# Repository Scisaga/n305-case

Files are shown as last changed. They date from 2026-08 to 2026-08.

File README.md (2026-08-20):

# N305 主板机械参考与可打印外壳

没有厂商机械图纸，也不意味着设计新外壳只能靠“打印、打磨、再猜一次”。这个项目从原机照片、卡尺读数和 PCB 基准出发，重建一套**可以检查、修改并重新生成**的 N305 小主机机械模型。

项目目前已经走到可以试装的阶段：仓库里既有适合二次设计的 PCB/主板 STEP、STL 参考，也有可以直接切片验证的 V2 上下壳。V2 不是最终成品，而是一版用于发现问题、收集实物反馈的工程样机——已经确认的尺寸进入 CAD，仍待验证的参数也完整保留来源和状态，方便每一次试打都能推动模型继续收敛。

如果你手上也有这块主板，可以直接下载模型试装，也可以基于主板参考设计自己的外壳。尺寸反馈、接口照片和结构改进都很有价值。

<p align="center">
  <a href="https://delightlylinux.wordpress.com/2025/07/24/gmktec-g3-fun-while-it-lasted/">
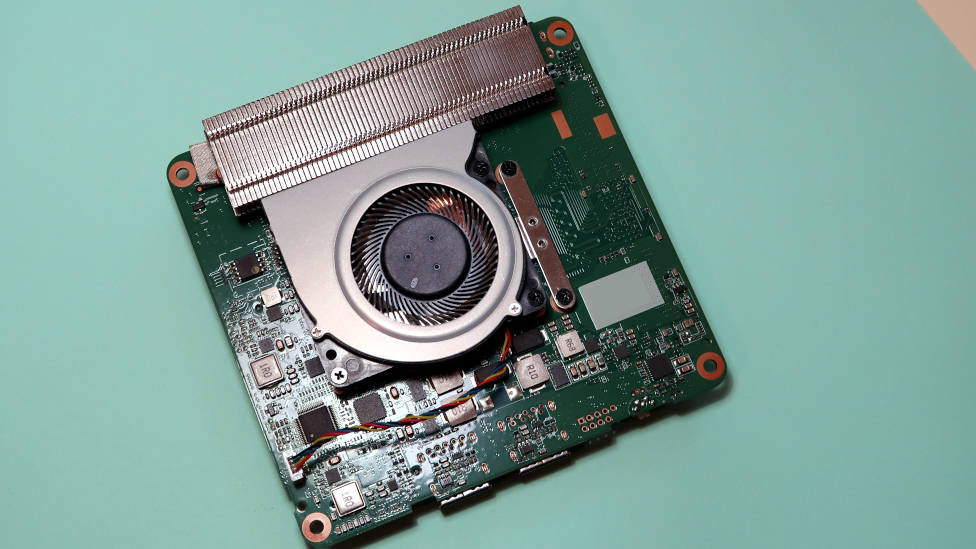
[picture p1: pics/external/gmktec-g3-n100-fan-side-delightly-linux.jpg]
GMKtec G3 主板的涡轮风扇与鳍片散热器一侧
    
  </a>
</p>

_外观参考：GMKtec G3 N100 版本主板的涡轮风扇与鳍片散热器一侧。图片来自 [Delightly Linux 原文](https://delightlylinux.wordpress.com/2025/07/24/gmktec-g3-fun-while-it-lasted/)；它与本项目重建对象布局相近，但不是本项目 N305 尺寸标定证据。机械尺寸仍以 `pics/` 中的用户实拍和卡尺数据为准。_

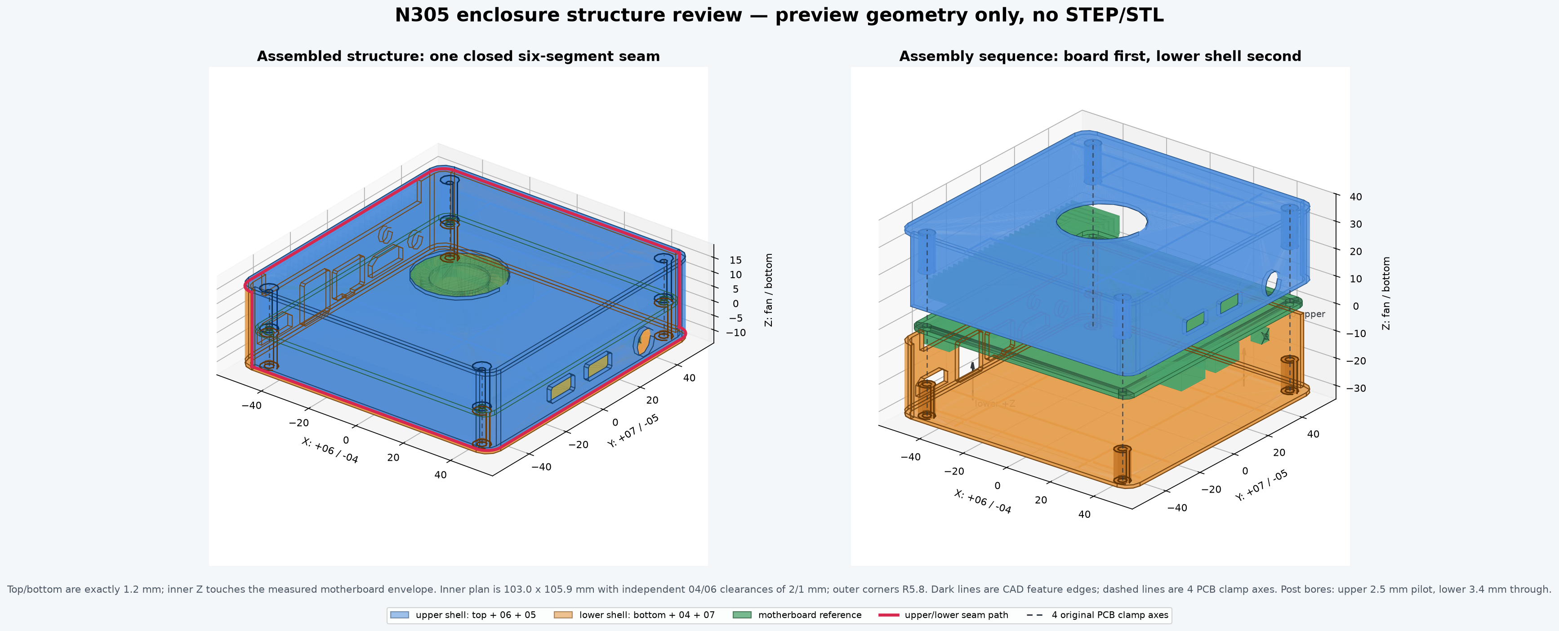
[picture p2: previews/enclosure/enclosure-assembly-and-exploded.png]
N305 V2 外壳装配与爆炸预览


_点击图片可在 GitHub 中打开 STL 交互预览；装配 STL 只用于检查，打印请使用独立的上壳和下壳文件。_

## 全程由 Codex 完成

这是一次用 [Codex](https://developers.openai.com/codex) 完成实体工程项目的实践。除实物拍摄、卡尺测量以及用户对方向和尺寸的确认外，照片证据整理、参数标定、建模代码、审阅图、STEP/STL 导出、自动验证和项目文档都由 Codex 在这个仓库中完成。

整个过程没有在 SolidWorks、Fusion 360、FreeCAD 等图形化专业 CAD 软件中手工建模或修补模型。Codex 编写并运行 Python/CadQuery 代码，底层使用 CadQuery、OpenCascade、Matplotlib、NumPy 和 Pillow 等开源程序库完成几何构造、图像处理和文件生成。因此，这里的 CAD 不是一组只能继续手工维护的成品文件，而是可以从参数和证据重新构建的程序化模型。

这也不是“一句话生成外壳”的演示。用户负责提供真实世界输入、识别明显错误并作出工程取舍；Codex 负责把这些反馈转化为参数、规则、代码和验证。最终结果来自多轮协作，而不是把 AI 的第一次推断当成答案。

## 快速入口

| 我想要…… | 从这里开始 |
| --- | --- |
| 直接试打 V2 外壳 | [上壳 STL](exports/enclosure/v2-prototype/n305_v2_upper_shell.stl) · [下壳 STL](exports/enclosure/v2-prototype/n305_v2_lower_shell.stl) · [试装说明](exports/enclosure/v2-prototype/README.md) |
| 选择材料和国内打印平台 | [V2 打印、下单与试装指南](docs/v2-printing-guide.md) |
| 修改 V2 外壳 | [上壳 STEP](exports/enclosure/v2-prototype/n305_v2_upper_shell.step) · [下壳 STEP](exports/enclosure/v2-prototype/n305_v2_lower_shell.step) · [参数源](src/n305_enclosure_structure.py) |
| 为主板设计自己的结构 | [完整主板 STEP](exports/reference/physical/n305_motherboard_reference.step) · [完整主板 STL](exports/reference/physical/n305_motherboard_reference.stl) · [主板模型说明](docs/motherboard-reference.md) |
| 检查尺寸和开孔依据 | [04 面参考](previews/reference/04-interface-reference.png) · [06 面参考](previews/reference/06-interface-reference.png) · [开孔覆盖检查](previews/enclosure/aperture-coverage-review.png) |
| 复现全部模型 | [构建脚本](scripts/) · [建模流程](docs/modeling-workflow.md) · [验证结果](exports/enclosure/v2-prototype/validation.json) |

## 当前进度

- [x] PCB 外形、四个原始安装孔和主板坐标系
- [x] 04/06 接口、板载开关和散热组件参考
- [x] 与物理实体分离的安装轴线和保守避让体
- [x] 面板开孔、圆角接缝和四孔夹紧结构审阅
- [x] 顶/底板 `1.5 × 0.8 mm` 内侧加强筋、器件绕行和碰撞审阅
- [x] V2 上壳、下壳及装配 STEP/STL
- [x] STEP 回读、STL 网格、实体边界和开孔覆盖自动验证
- [ ] V2 实物打印与同款主板装配反馈
- [ ] 收敛打印补偿、紧固件和按钮行程后发布制造版

## 方法与流程

这个项目最重要的产物不只是 STL，而是一套从不完整照片走向可审阅 CAD 的工作方法。顺序不能颠倒：先弄清楚证据说明了什么，再决定二维机械位置，最后才生成三维实体。

```mermaid
flowchart LR
    A[保存原始照片] --> B[记录实测与像素证据]
    B --> C[换算到统一 PCB 坐标]
    C --> D[生成正投影审阅图]
    D --> E{人工审阅}
    E -- 修正 --> B
    E -- 通过 --> F[生成 STEP / STL]
    F --> G[自动验证与实物试装]
    G -- 新实测 --> B
```

1. **保存原始证据**：原始照片保持不变，另外记录照片编号、观察方向、卡尺读数和可见轮廓。
2. **给数据分级**：明确区分用户实测、照片可读尺寸、PCB 对齐标定、轮廓证据和视觉推断；推断值必须标为 provisional。
3. **建立唯一坐标系**：以 `100.0 × 105.5 mm` PCB 和四个原始孔为机械基准，把照片信息换算成统一毫米坐标，不把画面边缘当作原点。
4. **先审二维机械图**：生成带 PCB 边界、方向、孔中心、尺寸和数据来源的正投影图，先检查接口位置与轮廓。
5. **审阅通过后再建三维**：CAD 直接读取毫米参数；物理实体、面板开孔、插头通道和保守避让体分开构造与导出。
6. **让验证成为模型的一部分**：回读 STEP、解析 STL，并检查包络、四孔、实体接触、开孔覆盖、壳体重叠和文件哈希。
7. **用试装结果闭环**：把装配松紧、接口插拔、按钮行程和紧固件结果重新写回参数，而不是只在 STL 上做一次性修补。

详细规则已经写入 [AGENTS.md](AGENTS.md)，完整操作见 [建模流程](docs/modeling-workflow.md)。这使后续 Codex 会话也必须遵守同一套坐标、数据优先级和审阅门。

## 走过的弯路

Codex 在早期重建中确实发生过多次漂移，用户的实测和审阅把模型拉回了正确轨道。这个过程也直接塑造了现在的方法论：

- 曾把照片透视和画面位置带入机械坐标，导致接口位置看似合理、实际基准却不可靠；后来强制所有位置先对齐 PCB。
- 曾把卡尺照片中的总包络差值平均分到 PCB 两侧，混淆了板宽和不同接口的突出量；后来改为按表面、按器件分别记录。
- 曾把通用 HDMI 代理当作真实接口鼻端，与已经确认的原壳六边形孔产生假冲突；现在未实测的真实轮廓明确标为“不计算”。
- 曾过早用简化形状替代散热器和风扇结构，也出现过看起来圆润但无法保持等壁厚、甚至不能完整包住 PCB 的外壳圆角方案。
- 曾在二维数据尚未稳定时直接推进三维，导致局部修正引发新的全局不一致；现在任何对象都必须先通过对应审阅门。

这些问题没有只靠修改最终模型掩盖。每次纠正都被固化成参数来源、生成规则或自动检查，目的是让同一种错误不再悄悄回来。仓库中的审阅记录因此不是附属文档，而是模型可信度的一部分。

## 设计预览

04 面的接口不是从照片像素直接描进 CAD，而是先换算到统一 PCB 坐标，再生成正投影审阅图：

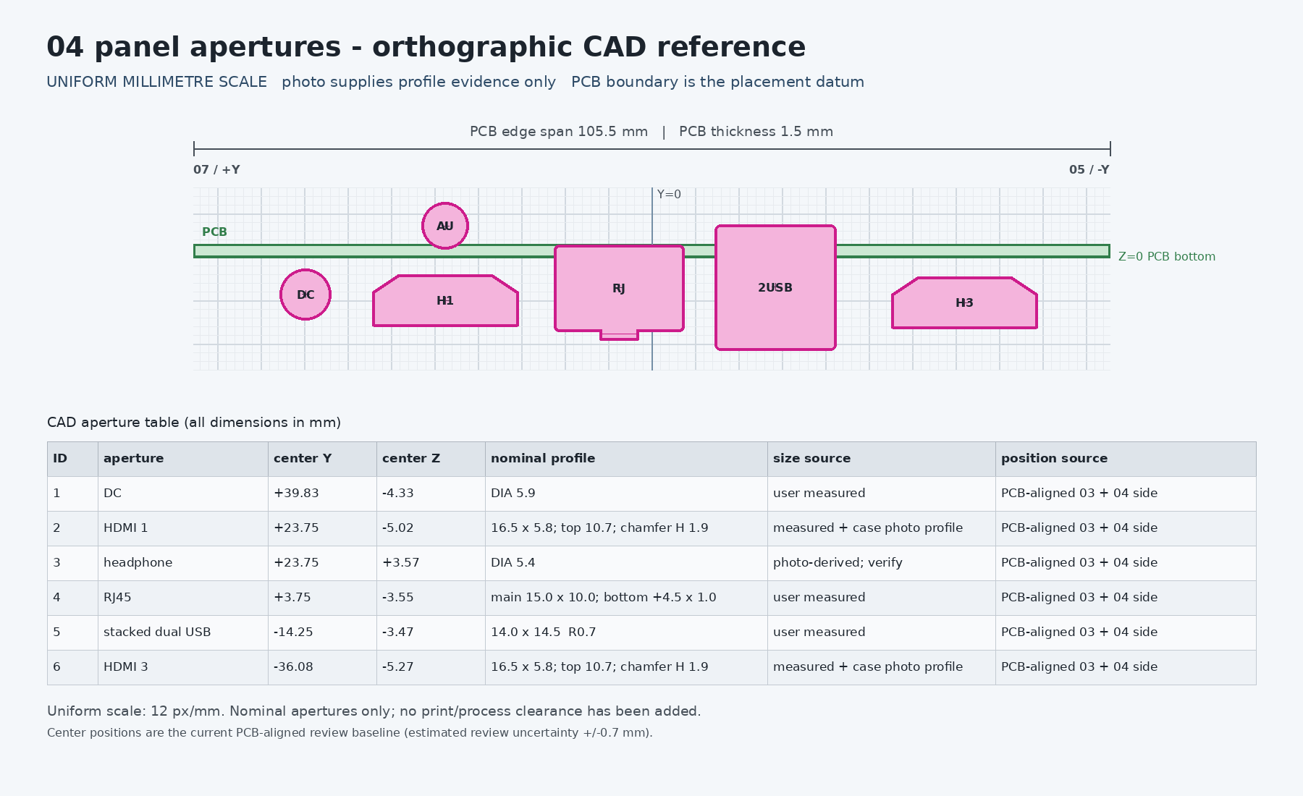
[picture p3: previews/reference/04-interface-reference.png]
04 面接口正投影审阅图


上下壳直接使用主板原有四孔定位和夹紧，不额外增加四颗外壳安装螺丝：

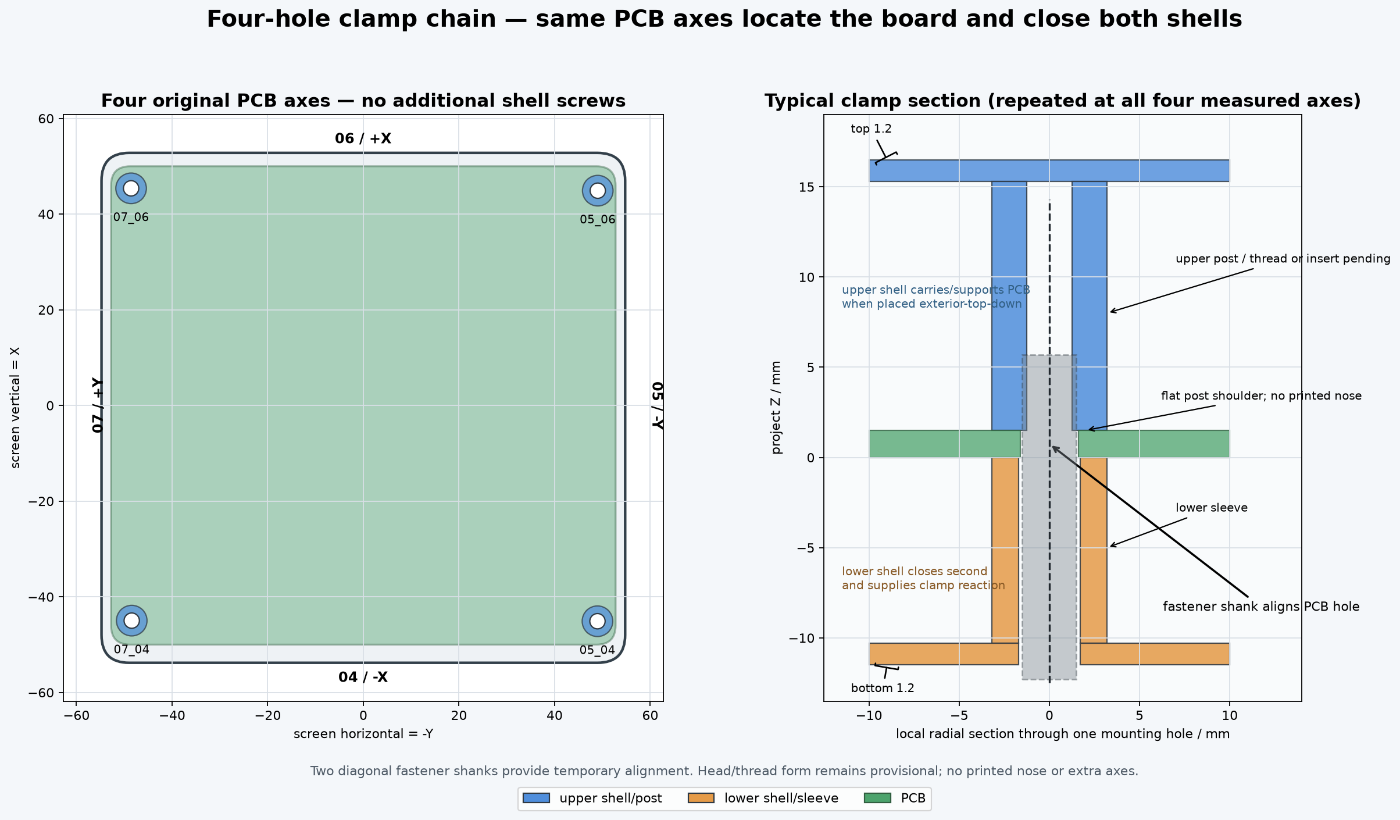
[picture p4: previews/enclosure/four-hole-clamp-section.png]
四孔夹紧结构剖面


顶板和底板的内侧加强筋也不是按外观随意布置。蓝色筋路已经用精确三维实体检查：顶筋绕过完整风扇蜗壳和鳍片，底筋绕过最低的 04 堆叠双 USB，并同时与完整主板参考进行碰撞审计。当前所有交叠体积均为 `0.000 mm³`。

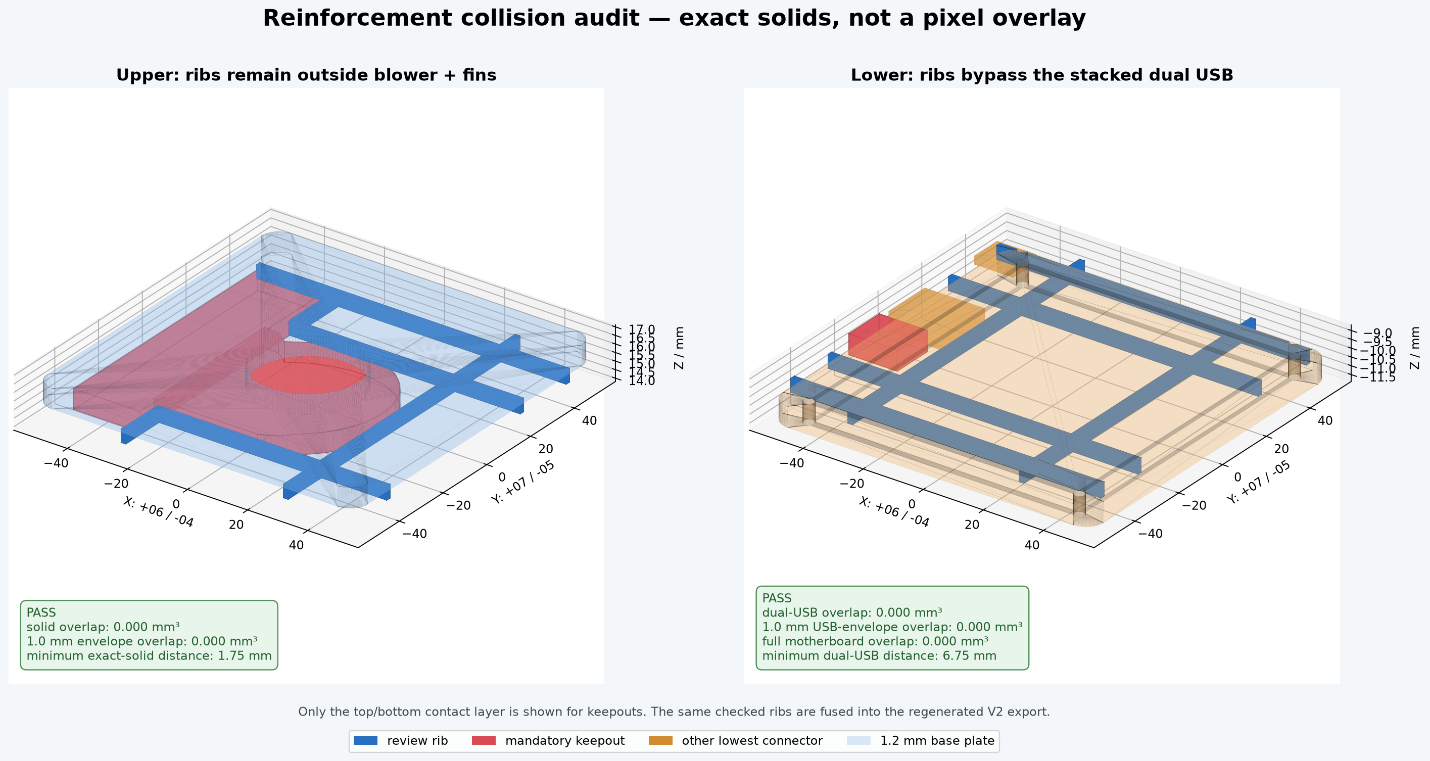
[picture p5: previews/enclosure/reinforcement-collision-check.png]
顶板和底板加强筋实体碰撞检查


具体筋路、尺寸和最短距离见 [加强筋审阅](docs/enclosure-reinforcement-review.md)。

更多结构图见 [外壳结构审阅](docs/enclosure-structure-review.md)，主板风扇、鳍片和散热接触关系见 [主板模型说明](docs/motherboard-reference.md)。

## 坐标与表面命名

项目文档中的 `04`、`05`、`06`、`07` 来自照片和实物表面的统一编号。正对风扇面、鳍片朝下时：

```text
                    06 / +X
                       ↑
          07 / +Y  ←  PCB  →  05 / -Y
                       ↓
                    04 / -X

             +Z 朝风扇，PCB 底面 Z=0
```

照片编号与观察方向见 [照片索引](pics/README.md)。所有 CAD 均使用毫米，并保持同一套装配坐标。

## 哪些尺寸可以相信

这个仓库刻意保留每项数据的来源和确定程度，不把视觉估算包装成精确测量。发生冲突时，用户实测和卡尺读数优先于照片标定，照片轮廓又优先于纯视觉推断。

当前 PCB 平面为 `100.0 × 105.5 mm`。PCB 外形、原始安装孔、接口中心和总 Z 包络用于机械定位；连接器隐藏壳体、PCB 圆角、散热器局部细节以及底面器件避让体仍包含照片重建或保守近似，不能当作厂商原始 CAD。

V2 外壳中的侧壁厚度、部分结构间隙、紧固件方案、打印补偿和按钮有效行程仍需要实物试装确认。完整参数及状态见 [V2 试装说明](exports/enclosure/v2-prototype/README.md)；数据权威顺序和建模规则见 [AGENTS.md](AGENTS.md)。

## 本地复现

需要 Python 3.11 或更高版本。以下命令会建立本地环境，并从参数和照片证据重新生成审阅图、主板模型与 V2 外壳：

```bash
python -m venv .venv
.venv/bin/python -m pip install -e .
PYTHONPATH=src .venv/bin/python scripts/calibrate_photos.py
PYTHONPATH=src .venv/bin/python scripts/calibrate_components.py
PYTHONPATH=src .venv/bin/python scripts/render_mainboard_reference.py
PYTHONPATH=src .venv/bin/python scripts/build_motherboard_reference.py
PYTHONDONTWRITEBYTECODE=1 PYTHONPATH=src .venv/bin/python scripts/build_enclosure_structure_review.py
PYTHONDONTWRITEBYTECODE=1 PYTHONPATH=src .venv/bin/python scripts/build_enclosure_reinforcement_review.py
PYTHONDONTWRITEBYTECODE=1 PYTHONPATH=src .venv/bin/python scripts/build_v2_prototype_enclosure.py
```

生成过程不仅导出 STEP/STL，也会回读 STEP、解析 STL 网格并写出验证 JSON。模型、参数和审阅材料分别放在：

- `src/`：机械参数和几何构造
- `scripts/`：标定、渲染、导出与验证入口
- `pics/`：原始照片证据
- `previews/`：适合人工审阅的正投影和结构图
- `exports/`：STEP、STL、参数清单与机器验证结果
- `docs/`：方法、数据来源和审阅记录

## 参与试装

当前最有价值的贡献是真实装配反馈。开始前请先阅读 [V2 试装建议](exports/enclosure/v2-prototype/README.md)，并尽量同时记录打印机、材料、层高和切片补偿。重点需要确认：

- 04/06 方向的壳体间隙，以及 05/07 方向的插入阻力
- 四个主板孔与上下壳柱体是否同轴
- USB、HDMI、RJ45、DC 和耳机插头能否顺畅插拔
- 原机圆形按钮的安装、行程和回弹
- 实际采用的螺钉、螺纹或热熔螺母方案

请不要为了“看起来能装”而默默修改模型；把实测值、测试条件和对应表面一起留下，下一版才能真正比这一版更可靠。

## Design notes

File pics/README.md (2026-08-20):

# N305 主板照片的视图与空间关系

本文说明本目录照片之间的空间关系，并为照片标定、尺寸提取和 CAD 建模提供统一方向。照片拍摄时存在旋转，**照片画面的上、下、左、右不等于主板的统一物理方位**；判断空间关系时以本页的“风扇面基准视图”为准。

## 1. 已确认的风扇面基准视图

正对风扇、热管和散热模组所在的元件面，并将散热鳍片转到下方。此时四条边的位置已经确认如下：

```text
                         上：06（双 USB 边）
                                CAD +X
                                   ↑
                                   │
 左：07（左边侧视）   CAD +Y  ←── 主板 ──→  CAD -Y   右：05（右边侧视）
                                   │
                                   ↓
                                CAD -X
                 下：04（后置 I/O、散热鳍片/出风边）

 +Z：离开 PCB，朝向观察者、风扇和热管
 -Z：穿过 PCB，朝向底面器件、M.2/内存插槽一侧
```

最重要的方位关系是：

- 左边是 07，上边是 06，右边是 05，下边是 04。
- 散热鳍片位于下方，即 04 所在边；04 同时是主要后置 I/O 边。
- 04 与 06 互为对边，05 与 07 互为对边。

### 与现有 CAD 坐标的关系

旧模型曾沿用原始照片方向，相对上述基准视图旋转了 90°。当前统一使用下列 CAD 坐标，不再保留旧生成器：

- CAD +X 指向基准视图上方的 06，CAD -X 指向下方的 04。
- CAD +Y 指向基准视图左方的 07，CAD -Y 指向右方的 05。
- `PCB_X = 100.0 mm` 对应基准视图的上下方向，即 06—04 方向。
- `PCB_Y = 105.5 mm` 对应基准视图的左右方向，即 07—05 方向。
- CAD +Z 指向风扇面，CAD -Z 指向主板底面。

坐标原点可取 PCB 平面中心；PCB 上、下表面的具体 Z 值由装配基准决定。

## 2. 六个面的对应关系

| 面或边 | 在风扇面基准视图中的位置 | 相机所在方向 | 观察方向 | 对面 | 识别特征 |
| --- | --- | --- | --- | --- | --- |
| 元件/风扇面 | 正面 | +Z | 沿 -Z 俯视 | PCB 底面 | 鼓风机、热管、长条散热鳍片 |
| PCB 底面 | 背面 | -Z | 沿 +Z 仰视 | 元件/风扇面 | M.2/内存插槽、纽扣电池及底面器件 |
| 04 边 | 下 | -X | 沿 +X 观察 | 06 边 | 后置 I/O 集中；散热鳍片和主要出风口位于此边 |
| 06 边 | 上 | +X | 沿 -X 观察 | 04 边 | 两个蓝色 USB-A 接口是最明显标志 |
| 05 边 | 右 | -Y | 沿 +Y 观察 | 07 边 | 主板右边的高度和侧面轮廓 |
| 07 边 | 左 | +Y | 沿 -Y 观察 | 05 边 | 主板左边的高度和侧面轮廓 |

因此有三组严格相反的观察方向：

- 元件/风扇面（+Z）与 PCB 底面（-Z）。
- 下边 04（-X）与上边 06（+X）。
- 右边 05（-Y）与左边 07（+Y）。

从风扇面翻到 PCB 底面后，左右关系会镜像。用底面照片标定孔位或器件位置时，应先通过四条已编号的边重新定向，不能直接沿用风扇面照片的画面左右坐标。

## 3. 照片与观察方向

| 照片 | 观察方向 | 内容与用途 |
| --- | --- | --- |
| [01-n305-mainboard-component-side-overall-width-measurement.jpg](./01-n305-mainboard-component-side-overall-width-measurement.jpg) | +Z → -Z | 风扇面整体尺寸；CAD X / 基准视图上下方向测量 |
| [02-n305-mainboard-component-side-overall-depth-measurement.jpg](./02-n305-mainboard-component-side-overall-depth-measurement.jpg) | +Z → -Z | 风扇面整体尺寸；CAD Y / 基准视图左右方向测量 |
| [03-n305-mainboard-bottom-side-overview.jpg](./03-n305-mainboard-bottom-side-overview.jpg) | -Z → +Z | PCB 底面总览；与风扇面互为正反面 |
| [04-n305-mainboard-bottom-rear-io-heatsink-edge-height-measurement.jpg](./04-n305-mainboard-bottom-rear-io-heatsink-edge-height-measurement.jpg) | -X → +X | 基准视图下边侧视；后置 I/O、鳍片/出风边及 Z 向高度 |
| [05-n305-mainboard-right-edge-height-measurement.jpg](./05-n305-mainboard-right-edge-height-measurement.jpg) | -Y → +Y | 基准视图右边侧视和 Z 向高度；与 07 相对 |
| [06-n305-mainboard-top-dual-usb-edge-height-measurement.jpg](./06-n305-mainboard-top-dual-usb-edge-height-measurement.jpg) | +X → -X | 基准视图上边侧视；双 USB 边及 Z 向高度；与 04 相对 |
| [07-n305-mainboard-left-edge-profile.jpg](./07-n305-mainboard-left-edge-profile.jpg) | +Y → -Y | 基准视图左边侧视和侧面轮廓；与 05 相对 |
| [08-n305-mainboard-component-side-blower-span-measurement.jpg](./08-n305-mainboard-component-side-blower-span-measurement.jpg) | +Z → -Z | 风扇面局部尺寸，记录鼓风机区域跨度 |
| [09-n305-mainboard-component-side-heatsink-span-measurement.jpg](./09-n305-mainboard-component-side-heatsink-span-measurement.jpg) | +Z → -Z | 风扇面局部尺寸，记录散热模组跨度 |
| [10-n305-mainboard-component-side-fin-stack-span-measurement-01.jpg](./10-n305-mainboard-component-side-fin-stack-span-measurement-01.jpg) | +Z → -Z | 鳍片区域跨度测量，第一张读数参考 |
| [11-n305-mainboard-component-side-fin-stack-span-measurement-02.jpg](./11-n305-mainboard-component-side-fin-stack-span-measurement-02.jpg) | +Z → -Z | 同一区域的第二张读数参考，用于交叉检查 |
| [机箱盒子04.jpg](./机箱盒子04.jpg) | 04 原机面板的一侧 | 反查 HDMI、RJ45、叠层窗口和 DC 的实际壳体开孔；其画面水平方向与产品外观图镜像 |
| [机箱盒子06.jpg](./机箱盒子06.jpg) | 06 原机外侧 | 反查两个 USB 开孔和已安装圆形按钮的位置/可见直径 |
| [机箱按钮-1.jpg](./机箱按钮-1.jpg) | 原机按钮正面 | 恢复圆帽与止挡法兰直径比例 |
| [机箱按钮-2.jpg](./机箱按钮-2.jpg) | 原机按钮侧面 | 恢复圆帽凸出和法兰厚度；后端推杆被便签遮挡 |

08～11 都是从 +Z 方向拍摄的局部测量照片，不是新增的独立表面。

### 第三方外观参考

| 本地副本 | 原始来源 | 用途与限制 |
| --- | --- | --- |
| [external/gmktec-g3-n100-fan-side-delightly-linux.jpg](./external/gmktec-g3-n100-fan-side-delightly-linux.jpg) | [Delightly Linux：GMKtec G3 – Fun While It Lasted](https://delightlylinux.wordpress.com/2025/07/24/gmktec-g3-fun-while-it-lasted/) · [原图](https://delightlylinux.wordpress.com/wp-content/uploads/2025/07/g3_rip05.jpg) | GMKtec G3 **N100** 版本主板的风扇/鳍片侧外观参考；不是本项目 N305 的尺寸标定证据，不进入像素测量或 CAD 参数源。 |

本地副本保持原图 `976 × 549` JPEG，SHA-256 为 `a1707353513bc608e8bfbca7035629bb3766b3975cc5d1438e5a57a8070ad939`。来源页面未展示明确的开放再许可条款，因此 README 必须保留来源链接和第三方属性；若来源方提出要求，应删除本地副本并恢复为外链展示。

## 4. Z 向堆叠关系

从 +Z 到 -Z，主板组件大致按以下顺序排列：

```text
最高处：风扇壳体、散热模组                 +Z
        热管、风扇、鳍片
        PCB 元件面
        PCB，厚约 1.5 mm
        PCB 底面器件、插槽及 SSD 避让区
最低处：底面最大下探器件                   -Z
```

当前项目使用的实测/建模值为：

- PCB 元件面至风扇最高面约 13.8 mm。
- PCB 厚度约 1.5 mm。
- PCB 底面至最低器件为 10.25 mm（04 原图换算值 10.246 mm）。
- 裸组件建模厚度为 25.55 mm，卡尺读数约 25.6 mm。
- 01 图约 `100.0 mm`、02 图约 `105.5 mm` 的卡尺读数确认 PCB 平面尺寸；卡爪位于角部，不能据此得到接口最大包络，也不能把差值对称分配给 04/06。
- 当前用户粗测为：04 双 USB 是该面最突出接口，约超出 PCB `2.0 mm`；06 两个 USB 约超出 `1.0 mm`；04 鳍片不超出 PCB。其余 04 接口只确认“略凸”，逐件突出量仍为 provisional。

散热气流的主要空间关系是：鼓风机从 +Z 侧吸气，经鳍片后朝基准视图下方的 04 边排出；在 CAD 中该方向为 -X。因此 V0.2 顶面圆孔直接对准风扇进气口，04 面设置与鳍片对齐的宽排风窗口；出风路径上不设置封闭横梁或小孔阵列。

01 照片中的风扇外壳已按 PCB 四角校正后描摩为非对称蜗壳，原始轮廓证据见 [01-blower-profile-trace.png](../previews/calibration/01-blower-profile-trace.png)，机器转换记录见 [component-calibration.json](../docs/component-calibration.json)。旧版 58 × 57 mm 圆角矩形风扇壳和三根叶轮示意杆作废。

## 5. 建模和照片标定规则

1. 先把风扇面照片旋转到“鳍片朝下”的基准姿态，再判断左 07、上 06、右 05、下 04。
2. 把基准视图方位录入现有 CAD 时使用转换关系：上/下对应 ±X，左/右对应 ±Y。
3. 使用底面照片时先做镜像关系检查，再通过接口组合或鳍片位置确认方向。
4. 两个相对侧视图的画面水平方向天然相反；比较接口位置时必须转换到同一个坐标系。
5. 03 底面照片先按 PCB 四条理论直边做透视校正，负责孔位和所有接口 XY；04、06 只负责 Z、接口正面形状和顺序。侧照片中的板边投影与接口不在同一深度，不能再拿来直接换算 Y。
6. 卡尺存在遮挡和透视误差；01、02 用于 PCB 平面尺寸，不能当成接口鼻端总包络。不同 Z 高度的接口和鳍片还会产生不同俯拍视差，不能直接用 PCB 平面单应结果反算突出量。08～11 用于局部尺寸和交叉验证。
7. 后续新增照片时，文件名应写明此基准下的方位和稳定特征，例如 `top-dual-usb-edge`、`bottom-rear-io-heatsink-edge`。
8. 完整像素坐标、换算式和辅助线叠图见 [../docs/photo-calibration.md](../docs/photo-calibration.md)。

## 6. 电源开关照片标定

03 底面照片透视校正并用 06 侧照片复核后，当前审阅基准为：

- 开关位于 06 边，与两个蓝色 USB-A 位于同一面。
- 开关中心为 `Y≈+29.5 mm`，沿 06 边距 07/06 角约 23.3 mm。
- 等价地，距 05/06 角约 82.3 mm。
- 开关中心约在 PCB 底面以下 4.2 mm。
- 可见开关正面约 4.5 × 4.5 mm，中央触点约 1.6～2.0 mm。

静态照片不能直接测得真实触发行程。原机 06 面照片和按钮照片支持恢复圆形按钮：可见帽约 Ø10.0 mm、止挡法兰约 Ø12.5 mm；用户实测穿过面板孔的按钮段为 **Ø9.2 mm**，原壳/新壳采用 **Ø9.4 mm** 配合孔。侧视照片中后端推杆被便签遮挡，不能从该图直接量取推杆长度。

[03 底面俯视照片](./03-n305-mainboard-bottom-side-overview.jpg) 与 [06 侧视照片](./06-n305-mainboard-top-dual-usb-edge-height-measurement.jpg) 共同确认：两个 USB 金属口构成06面的外侧接口基准；开关触点比 USB 前沿约向内退 `1.2 mm`（照片推定，暂记 ±0.4 mm），相邻 PCB 边还有局部台阶内缩。因此不能用 `100 mm` PCB 外接矩形的 `X=50` 直边直接推出开关触点位置，也不能把开关触点当作必须伸入 Ø9.4 墙孔的对象。按当前 USB 突出 `1.0 mm` 代理，开关触点暂置于 `X≈49.8 mm`；结合原壳 04–06 内距约 `103.0 mm`，06内墙暂置于 `X=51.0 mm`，两者约有 `1.2 mm` 静止轴向空间，后续由原按钮推杆跨越。

该标定取代早期“开关位于 05 边、距照片左边约 32 mm”的错误假设。

两只 USB-A 中心分别为 `Y≈+4.75 mm` 与 `Y≈-15.25 mm`。它们是同层安装的相同器件，因此机械参考共享 `Z=-3.14 mm`；此前 `-3.19/-3.09 mm` 的差值来自斜拍照片的透视推算，已经撤销。两个面板孔均采用用户确认的 **12.8 × 5.5 mm、R0.7** 水平圆角矩形；旧版 13.3/13.4 × 6.0 mm 以及 15.4 × 7.8 mm 孔作废。

## 7. 04 接口面的逐像素结论

[04-n305-mainboard-bottom-rear-io-heatsink-edge-height-measurement.jpg](./04-n305-mainboard-bottom-rear-io-heatsink-edge-height-measurement.jpg) 的卡尺主刻线拟合比例是 20.3 px/mm。结合主板照片与原机面板上方的接口图标，沿边组合确认是：DC、HDMI、RJ45、上下叠层双 USB-A、HDMI；此前把下层误认作 HDMI 的结论作废。

03 校正平面给出的中心 Y 为 `+39.83 / +23.75 / +3.75 / -14.25 / -36.08 mm`。这些中心对原机 04 面板五孔的线性拟合最大残差为 0.634 mm，所以中心位置保留。面板孔尺寸采用用户后续确认的实测值：DC **Ø5.9**；两只 HDMI **16.5 × 5.8** 原壳六边形，顶边 10.7、倒角高 1.9；叠层双 USB 共用 **14.0 × 14.5、R0.7** 圆角窗口；RJ45 主窗 **15.0 × 10.0**，其下方另加 **4.5 × 1.0** relief。原壳照片只用于确认非矩形轮廓，没有使用通用 HDMI 标准轮廓。

05、07 照片没有显示侧向插拔的用户接口，因此这两面保持封闭。

## 8. 与 V0.2 分壳的关系

V0.2 使用两个由三相邻面构成的互补角壳：

- 上壳：顶面、06、05，包含双 USB 和按键。
- 下壳：底面、04、07，包含后置接口和排风开口。

装板时先把 06 边 USB 斜向送入上壳窗口，再放平主板和安装下壳。四个 PCB 安装孔轴同时连接主板及两壳，不设置额外壳体螺丝位。04、06 各自保留一整面带贯通开孔的连续实体墙，不承担贴边定位；原壳实测 04–06 内距约 `103.0 mm`，结合 04/06 USB 最大突出量暂分配为 `2.0/1.0 mm`。05/07 仍各留 `0.20 mm` 紧凑试装余量；原壳约 `110.5 mm` 的 05–07 内距包含无需复制的额外留空。侧壁厚采用原壳实测 `1.8 mm`。连续内搭边和连续卡槽已经从方案中取消，六段异件边采用平面对接；详细结构见 [../docs/v0.2-reference-review.md](../docs/v0.2-reference-review.md)。

## 9. 关系确认状态

- 风扇面与 PCB 底面的正反关系：已确认。
- 风扇面基准视图中的左 07、上 06、右 05、下 04：已由实物方位确认。
- 散热鳍片位于下方 04 边，04 与 06 相对：已确认。
- 05 与 07 相对：已确认。
- 板载电源开关位于 06 边且偏向 07/06 一侧，当前中心 `Y≈+29.5 mm`：已由 03 校正平面与 06 局部比例交叉检查；像素标定中心误差估计约 ±0.35 mm。
- “后置 I/O”是本项目采用的功能名称；若厂商资料使用其他前后命名，编号 04～07 和上述空间关系仍保持不变。

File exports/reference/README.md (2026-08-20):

# 主板参考导出

本目录由 `scripts/build_motherboard_reference.py` 生成。所有模型使用毫米和项目唯一坐标系：`+X=06`、`-X=04`、`+Y=07`、`-Y=05`、`+Z=风扇面`，PCB 底面为 `Z=0`。

## physical

- `n305_motherboard_reference.step/.stl`：PCB、接口、板载开关和散热组件的总装参考。
- `n305_pcb.step/.stl`：带四个安装孔的 PCB。
- `n305_connectors_and_switch.step/.stl`：04/06 接口实体和板载电源开关。
- `n305_cooling_assembly.step/.stl`：冷板支撑、风扇托板、照片描摩蜗壳、32 片叶轮、热桥和鳍片；不含缺少侧视高度证据的双孔长条。

这些文件是用于机壳设计的物理参考，不是厂商制造模型。连接器隐藏壳体和散热组件细节含照片估计。接口 X 向前沿按对象保存：04 双 USB 约突出 PCB 2.0 mm、06 USB 约突出 1.0 mm、04 鳍片与 PCB 边齐平；04 其余接口当前 1.0 mm 前伸仅是 provisional 外观代理，不是实测值。

## clearances

- `n305_cooling_keepout.step/.stl`：风扇与鳍片上方保守包络。
- `n305_underside_keepouts.step/.stl`：底面器件的保守避让包络。
- `n305_mount_axes.step/.stl`：四个 PCB 孔的装配轴线。

避让体不能与 `physical` 文件合并后当作实物体积使用。

## validation.json

记录数据源、PCB/孔位、Z 包络、接口参数、各零件边界和散热接触检查。当前检查必须全部通过，且 `enclosure_geometry_generated` 必须为 `false`，表示本主板参考包不混入外壳实体；独立的 V2 外壳位于 `exports/enclosure/v2-prototype/`。

重新生成：

```bash
PYTHONPATH=src .venv/bin/python scripts/build_motherboard_reference.py
```

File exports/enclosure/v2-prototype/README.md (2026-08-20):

# N305 V2 试装版外壳

发布日期：2026-08-21
版本：`v2-prototype-2026-08-21-ribbed`
状态：**用于尺寸、接口和装配试装，不是最终量产版。**

材料选择、国内平台下单、切片方向、螺钉和收货验收见 [V2 外壳打印、下单与试装指南](../../../docs/v2-printing-guide.md)。

> 若已经把同名 STL 上传到打印平台，必须删除旧文件并重新上传本次生成文件。当前含筋版预览体积应约为：上壳 `24.13 cm³`、下壳 `23.02 cm³`；文件同名不表示平台中的旧上传已经更新。

## 文件

- `n305_v2_upper_shell.step/.stl`：上壳，顶面 + 06 + 05。
- `n305_v2_lower_shell.step/.stl`：下壳，底面 + 04 + 07。
- `n305_v2_enclosure_assembly.step/.stl`：上下壳闭合位置，仅用于总体检查；打印时使用两个独立 STL。
- `manifest.json`：完整参数、文件哈希和数据来源。
- `validation.json`：源实体、导入 STEP、STL 网格和装配检查。

所有 CAD 均为毫米，保留项目装配坐标：`+X=06, -X=04, +Y=07, -Y=05, +Z=风扇面`。原机圆形按钮作为复用件，不生成未经测量的按钮 STL。

## 当前试装结构

- 外包络：`106.6 × 109.5 × 28 mm`。
- 上下板厚均为 `1.2 mm`；没有额外风扇顶部避让。
- 顶板/底板内侧已融合 `1.5 × 0.8 mm` 稀疏加强筋；局部总厚度为 `2 mm`，外包络不变。顶筋绕过完整风扇/鳍片包络，底筋绕过 04 堆叠双 USB 和当前完整主板参考。
- 04/06 是连续实体墙；原壳实测内跨距约 `103.0 mm`，结合接口突出量暂分配为 04 侧 `2.0 mm`、06 侧 `1.0 mm`。
- 05/07 各保留 `0.20 mm` 紧凑试装余量；原壳约 `110.5 mm` 的内跨距包含额外留空，不复制到本版。
- 四周侧壁采用原壳实测 `1.8 mm`；这些侧面仍不承担主板主要定位，主板由原四孔/螺柱定位。
- 使用主板原有四孔夹紧上下壳；没有增加外壳专用螺钉轴。
- 04 面保留连续鳍片出风包络；05/07 不开侧向接口孔。
- STL 网格：线性公差 `0.04 mm`，角公差 `0.12 rad`。

## 全部 provisional / 试制参数

| 参数 | 当前值 | 状态 | 来源与限制 |
| --- | ---: | --- | --- |
| `inner_x_at_04_06` | 103.0 mm | user approximate measurement | original case: face 04 inner wall to face 06 inner wall |
| `inner_y_at_05_07` | 105.9 mm | fit-check design | PCB 105.5 + 0.2 mm allowance at faces 05 and 07; original-case 110.5 mm span deliberately not copied |
| `side_wall_thickness` | 1.8 mm | user measured | original case side wall; Not applied to panel aperture sizes. |
| `outer_plan_corner_radius` | 5.8 mm | derived provisional | inner PCB radius + side-wall thickness; Constant-thickness XY offset; replaces the invalid R10 corner. |
| `inner_plan_corner_radius` | 4.0 mm | provisional | photo-reconstructed motherboard corner radius; Must be replaced if a physical corner measurement differs. |
| `pcb_clearance_face_04` | 2.0 mm | derived provisional allocation | 2.0 mm maximum 04 USB projection and 103.0 mm measured inner span; Inner wall coincides nominally with the maximum USB front plane; it is not a PCB locating face. |
| `pcb_clearance_face_06` | 1.0 mm | derived provisional allocation | remaining 1.0 mm of the measured 103.0 mm inner span; Matches the 1.0 mm USB projection; the recessed switch is not the wall datum. |
| `pcb_clearance_face_05` | 0.2 mm | user-requested fit-check allowance | compact non-locating clearance; original-case 110.5 mm span includes unnecessary extra space |
| `pcb_clearance_face_07` | 0.2 mm | user-requested fit-check allowance | compact non-locating clearance; original-case 110.5 mm span includes unnecessary extra space |
| `original_button_through_diameter` | 9.2 mm | user measured | diameter of the original button portion that passes through the panel |
| `face_06_switch_tip_to_inner_wall` | 1.2 mm | photo-derived provisional | photo 03 places the switch behind the USB-defined wall datum; positive means no switch/wall penetration |
| `connector_front_span_04_to_06` | 103.0 mm | derived cross-check | PCB 100.0 + face-04 USB projection 2.0 + face-06 USB projection 1.0; equals the measured inner span |
| `button_inner_wall_to_switch_tip_range` | 0.8 × 1.6 mm | photo-derived estimated range | nominal 1.2 mm with +/-0.4 mm switch-plan uncertainty; excludes unquantified USB rough-measurement error |
| `button_outer_wall_to_switch_tip_range` | 2.6 × 3.4 mm | derived estimated range | 1.8 mm measured wall plus the inner-wall-to-switch range; original button must bridge this axial stack |
| `face_04_max_connector_projection` | 2.0 mm | user rough measurement | stacked dual USB maximum; not shared by every 04 connector |
| `face_04_other_connector_projection_proxy` | 1.0 mm | provisional | unmeasured 04 connector noses; Visual proxy only; DC, HDMI, headphone and RJ45 front projections are not individually measured. |
| `face_06_usb_projection` | 1.0 mm | user rough measurement | two USB front faces; independent from face 04 |
| `nominal_seam_gap` | 0.0 mm | design intent | flush review geometry |
| `manufacturing_seam_clearance` | 0.0 mm | not applied | no manufacturing gap is embedded in the review geometry; any future process compensation must be a separate parameter |
| `fin_exhaust` | 84.0 × 7.4 mm | functional envelope | current fin-stack projection; grille segmentation pending |
| `internal_reinforcement_rib_height` | 0.8 mm | fit-check design | selected after PA12 manufacturability and collision review; Added locally to the 1.2 mm inner plate faces; does not change the base plate thickness. |
| `internal_reinforcement_rib_width` | 1.5 mm | fit-check design | reviewed sparse rib paths; Upper paths bypass the blower/fins; lower paths bypass the stacked dual USB and complete motherboard reference. |
| `clamp_post_od` | 6.4 mm | provisional | review proposal |
| `upper_thread_pilot_diameter` | 2.5 mm | provisional | review proposal; Thread, heat-set insert or self-tapping strategy is not selected. |
| `lower_screw_clearance_diameter` | 3.4 mm | provisional | review proposal; No screw-head counterbore or countersink is included. |
| `printed_hole_locator_nose` | no  | review recommendation | removed: 3.0 OD around 2.5 pilot leaves only 0.25 mm radial wall |
| `fastener_family` | M3-class  | provisional | inferred from 3.2 mm PCB hole; Head, insert and thread form pending. |

## 尚未解决、必须通过实物试装确认

- 04/06 allocation is provisionally 2.0/1.0 mm from USB projections
- exact photo-derived contour of the local PCB step beside the face-06 switch; the current full PCB envelope is conservative for wall clearance
- physical confirmation of the provisional PCB R4 corner reference
- additional print/process compensation, if later required, must remain separate from the reviewed structural clearance
- M3-class screw head, insert and thread form
- reused external button cap geometry and effective travel
- headphone aperture physical diameter confirmation
- exact HDMI connector-front profile; generic motherboard proxy is excluded from aperture coverage
- 04 fin-exhaust grille segmentation inside the no-obstruction envelope

补充说明：两个 HDMI 沿用已审阅的原壳六边形贯通孔。由于真实 HDMI 金属鼻端轮廓尚未测量，它们不参与“通用鼻端代理”的覆盖判定，但也没有因此改变孔形。

## 自动验证摘要

- 上壳、下壳各为一个有效实体：`True`。
- 上下壳体积重叠为零：`True`。
- 两壳与 PCB 实体体积重叠为零：`True`。
- 04/06 开孔后仍为连续墙体：`True`。
- 内侧加强筋已完整融合且无主板碰撞：`True`。
- STEP 回读实体数与体积一致：`True`。
- STL 文件可解析且包含三角形：`True`。
- 名义开孔覆盖失败：`[]`。
- 未计算覆盖：`['04:hdmi_1', '04:hdmi_3']`。

## 试装建议

1. 本目录未提供独立测试片；下单时打印上、下壳两个独立 STL，不打印装配 STL。
2. 上壳建议外顶面朝打印平台；下壳建议外底面朝打印平台。支撑策略取决于材料和切片软件。
3. 不要先强行攻丝。先测量实际 M3 紧固件、打印孔收缩和原按钮行程，再决定扩孔、热熔螺母或自攻方案。
4. 试装反馈应分别记录 04/06 间隙、05/07 插入阻力、四孔同轴性、按钮回弹和每个插头的插拔空间。

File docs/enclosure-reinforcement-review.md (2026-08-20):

# N305 外壳内侧加强筋审阅

状态：**路径和高度已经审阅，并已进入重新生成的 V2 STEP/STL。**

## 输出

- [顶板/底板内侧平面图](../previews/enclosure/reinforcement-inner-plan.png)
- [三维碰撞检查图](../previews/enclosure/reinforcement-collision-check.png)
- [机器验证结果](enclosure-reinforcement-validation.json)

## 当前设计

- 顶板、底板基础厚度继续保持 `1.2 mm`。
- 筋宽 `1.5 mm`，筋高 `0.8 mm`；已选择 `0.8 mm` 而不是初稿 `0.5 mm`，以提高 PA12 MJF/SLS 成型稳定性。
- 顶筋绕过照片重建的完整风扇蜗壳和 `84 × 22 mm` 鳍片投影。
- 底筋绕过 04 面堆叠双 USB；下层 USB 最低约 `Z=-10.29 mm`，与底板内表面 `Z=-10.30 mm` 基本齐平，不能依赖高度错开。
- 同时检查当前完整主板实体及其他接近底板的接口代理，不能为了满足单一 USB 避让而制造新的干涉。
- `1.0 mm` 是本审阅使用的保守 XY 包络，不是已写入外壳的制造间隙。

## 碰撞结果

| 检查 | 结果 |
| --- | ---: |
| 顶筋 vs 风扇/鳍片实体 | `0.000 mm³` |
| 顶筋 vs 1.0 mm 散热审阅包络 | `0.000 mm³` |
| 顶筋 vs 完整主板参考 | `0.000 mm³` |
| 底筋 vs 堆叠双 USB | `0.000 mm³` |
| 底筋 vs 1.0 mm 双 USB 审阅包络 | `0.000 mm³` |
| 底筋 vs 完整主板参考 | `0.000 mm³` |
| 顶筋至散热实体最短距离 | `1.75 mm` |
| 底筋至双 USB 实体最短距离 | `6.75 mm` |

当前全部布置检查通过：`True`。

## 已确认的制造取舍

筋高最终采用 `0.8 mm`。基础顶板/底板仍是 `1.2 mm`；只有筋路位置的局部总厚度为 `2.0 mm`。路径或高度以后若再次变化，仍必须重新执行实体碰撞检查和 STEP/STL 回读验证。

本设计没有增加外部包络、没有改变风扇进气孔，也没有改变顶板/底板的基础厚度。

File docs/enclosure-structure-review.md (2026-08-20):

# N305 外壳结构定义审阅

更新日期：2026-08-21

状态：**结构检查已通过，并已按本参数源生成 V2 试装版 STEP/STL；尚不是最终量产版。**

本文件记录“外壳由哪些面组成、怎样装配、怎样夹紧、接缝在哪里、开孔能否覆盖功能区域”。同一参数源现已用于用户授权的 V2 试装版；预览图本身仍不是制造文件，实际 CAD 与全部试制参数见 [V2 伴随说明](../exports/enclosure/v2-prototype/README.md)。

## 1. 两个一体式三面壳

| 零件 | 一体连接的面 | 作用 |
| --- | --- | --- |
| 上壳 | 顶面、06、05 | 先接收并承托主板；顶面带风扇进气孔 |
| 下壳 | 底面、04、07 | 第二步闭合；04 带接口和鳍片出风，底面提供四孔紧固入口 |
| 原机按钮 | 复用，不重画未经测量的帽体 | 穿过 06 的 Ø9.4 孔触发板载开关 |

[装配与爆炸图](../previews/enclosure/enclosure-assembly-and-exploded.png)使用蓝色表示上壳、橙色表示下壳、绿色表示主板参考。

## 2. 包络和壁厚

| 参数 | 当前值 | 状态与依据 |
| --- | ---: | --- |
| 内腔宽 X / Y | 约 103.0 / 105.9 mm | X 为用户对原壳的实测；Y 为 PCB 105.5 + 05/07 各 0.20 mm 试装余量 |
| X 向外宽 | 106.6 mm | derived：内腔 103.0 + 两侧 1.8 mm 壁 |
| Y 向外宽 | 109.5 mm | derived：内腔 105.9 + 两侧 1.8 mm 壁 |
| 裸组件 Z 包络 | -10.3…+15.3 mm | 当前主板验证包络，合计 25.6 mm |
| 顶板 / 底板 | 1.2 / 1.2 mm | 用户确认，精确值 |
| 内侧加强筋 | 宽 1.5 / 高 0.8 mm | 已审阅并进入 V2；有筋处局部总厚度 2.0 mm |
| 壳体 Z 向外厚 | 28.0 mm | 25.6 + 1.2 + 1.2；没有风扇额外间隙 |
| 侧壁 | 1.8 mm | 用户对原壳的实测；不改变面板孔标称尺寸 |
| XY 外轮廓圆角 | R5.8 mm | derived provisional：内 R4 + 1.8 mm 壁厚，构成等壁厚偏置 |
| XY 内腔圆角 | R4 mm | provisional：照片重建的 PCB 圆角，尚无物理实测值 |

顶板和底板的 `1.2 mm` 是连续基础板厚，不因加强筋而改写。已批准的稀疏筋从内表面增加 `0.8 mm`：顶筋在 XY 平面绕开完整风扇蜗壳和鳍片投影，底筋绕开最低的 04 堆叠双 USB，并同时对当前完整主板实体检查。实体交叠均为 `0.000 mm³`；筋已经与各自壳体融合为单一有效实体，不增加外包络。路径、距离和三维审图见[加强筋审阅](./enclosure-reinforcement-review.md)。

04 和 06 都是连续实体侧壁，只从整面墙中切除已经审阅的贯通孔和 04 鳍片出风包络。它们不承担 PCB 贴边定位。原壳 04–06 内距约 `103.0 mm`，当前结合两侧最大 USB 突出量暂分配为：04 内壁 `X=-52.0 mm`（距 PCB `2.0 mm`），06 内壁 `X=+51.0 mm`（距 PCB `1.0 mm`）。这使两侧 USB 前沿分别成为对应墙面的局部轴向基准，而不是让板载开关伸进墙体。

原壳 05–07 内距约 `110.5 mm` 包含额外留空，用户明确认为不需要参考，因此不进入当前外壳尺寸。05/07 恢复为各 `0.20 mm` 紧凑试装余量，当前 Y 向内距为 `105.9 mm`。PCB 的主要 XY 定位与两壳夹紧仍由原有四孔/螺柱完成。这些侧向尺寸不是上下壳接缝，也不是额外打印补偿。

接口突出量不再共享一个对称平面：04 叠层双 USB 粗测约 `2.0 mm`，06 两个 USB 粗测约 `1.0 mm`，04 鳍片外沿与 PCB 齐平；04 其余接口暂用 `1.0 mm` provisional 代理。按当前分配，两侧最大 USB 前沿都与内墙面名义相齐，在 `1.8 mm` 厚墙孔内形成与原壳一致方向的退入式接口通道，而不是让接口主体穿透整面墙。

03 俯视和 06 侧视共同确认 06 墙面轴向关系应由两个 USB 约束；开关触点比 USB 前沿约内退 `1.2 mm`，当前代理位于 `X≈49.8 mm`，距 06 内墙 `X=51.0 mm` 约 `1.2 mm`，不会进入墙孔。开关附近 PCB 的局部内缩轮廓不能再被 `100 mm` 外接矩形替代。`Ø9.4 mm` 按钮孔覆盖的是 `Ø9.2 mm` 原按钮穿孔段，不是板载触点本体。侧壁厚也已复原为原壳实测 `1.8 mm`，因此按钮的穿墙长度条件比旧版 `1.2 mm` 假设更接近原件；按钮静止位置与有效行程仍需实物试按确认。

当前主板实体仍保留 `100 × 105.5 mm` 完整外包络作为保守碰撞体，没有凭照片猜切局部 PCB 台阶的精确轮廓；但开关实体和墙面基准已脱离这条虚构直边。因为完整外包络比真实内缩 PCB 更占空间，只要它与墙体无碰撞，补回真实台阶不会恶化外壳净空。后续若需要外观级主板复刻，再单独对 03 照片做局部正投影描边。

四孔进一步锁定了这个推导。04 侧两根安装轴到 `X=-52.0 mm` 内墙分别约为 `7.018/6.893 mm`；06 侧两根安装轴到 `X=+51.0 mm` 内墙分别约为 `5.613/6.105 mm`。上下壳的柱位读取这些原孔坐标后，主板不能再沿 X 平移，因而不会把开关意外推入按钮孔。同时，`100.0 + 2.0 + 1.0 = 103.0 mm`，PCB 与两侧最大 USB 前沿的总跨度恰好闭合原壳内距。

按钮轴向链的当前估算为：外墙到内墙 `1.8 mm`，内墙到触点名义 `1.2 mm`，所以外表面到开关触点名义约 `3.0 mm`。只计 03 照片给出的 `±0.4 mm` 平面不确定度，内墙到触点约为 `0.8–1.6 mm`，外表面到触点约为 `2.6–3.4 mm`；这里尚未计入 USB“约 1 mm”粗测误差。原按钮本来就是为 `1.8 mm` 原壳墙厚和该主板安装关系工作的，因此复用的几何可信度较高；唯一不能由现有照片直接证明的仍是被遮挡推杆的自由长度与实际触发行程。

主板参考中的隐藏连接器主体只是保守方盒，并非实测轮廓。把 04/06 面退到 PCB 边后，这些代理方盒会与面板发生名义交叠；本轮只记录该交叠，不用它擅自放大原壳孔。实体检查改为：PCB 本体与六面零体积穿插、非接口面与完整主板模型无交叠、外部孔仍按权威尺寸完成覆盖。真实连接器后部若影响最终壁厚，需要补充实测截面后再处理。

圆角是真实参数化实体，不是渲染修饰。先前的“外 R10 + 内 R4 + 小幅外扩”并不满足包含关系，而旧验证只检查体积相交，错误地给出通过。本版已经删除该组合。现在外轮廓是扩大后的内腔轮廓向外等距 `1.8 mm` 的结果，因此外圆角为 `R4 + 1.8 = R5.8`，直边和圆角的名义壁厚一致。R4 仍是待实测的 provisional 内腔圆角，不表示圆弧与 PCB 零间隙接触。

新增验证同时检查：完整 PCB 平面是否被扩大后的内腔包含、04–06 内跨距是否为 `103.0 mm`、05/07 是否各为 `0.20 mm`、侧壁是否为 `1.8 mm`、06 内墙是否采用 USB 前沿而非开关触点作为基准、非对称 X 边界是否正确平移整个圆角实体、外轮廓与内腔理论等距偏置是否双向一致，以及开孔后 04/06 是否仍各为一个连续墙体实体。这些项目不能再由“PCB 与壳体相交体积为零”替代。PCB R4 本身仍是照片近似，待实物测量后会联动更新内外两个圆角。

当前验证要求为：PCB 完全位于内腔中；04/06 分配为 `2.0/1.0 mm`，05/07 为 `0.20/0.20 mm`；理论等距偏置相对当前外轮廓的缺失和多余体积均为 `0.0 mm³`；直边壁厚和圆角径向壁厚均为 `1.8 mm`；04/06 开孔后分别保持单一连续实体。最终数值以本轮重新生成的 [内部验证](./enclosure-structure-validation.json) 为准。

## 3. 一条闭合六段接缝

上下壳的边界是一条闭合路径：

```text
顶面—04 → 顶面—07 → 06—07 竖角 → 底面—06
     → 底面—05 → 04—05 竖角 → 回到顶面—04
```

- 两个右侧圆角（06/07、06/05）完整归 06/上壳；两个左侧圆角（04/07、04/05）完整归 04/下壳，任何圆角曲面上都没有分件缝。
- 06/07 竖缝退到 `X=+47.0 mm` 的 +Y 直边切点；04/05 竖缝退到 `X=-48.0 mm` 的 -Y 直边切点。两值不再强制关于原点对称，因为 04/06 单侧分配是 `2.0/1.0 mm`。
- 顶面/04、顶面/07、底面/06、底面/05 使用齐平对接；圆角转弯属于对应的完整单壳实体。
- 上壳内部的顶面—06—05，以及下壳内部的底面—04—07，均为同一零件的连续连接，不是装配缝。
- 当前名义 CAD 缝隙为 `0.0 mm`，没有嵌入制造补偿。若以后打印工艺确实需要补偿，必须另设参数并再次审阅，不能污染零间隙结构基准。
- 不使用连续卡槽、连续内搭边、整圈舌槽或独立框架。

详见 [六面归属和接缝图](../previews/enclosure/face-ownership-and-seam.png)。

爆炸图中圆角会完整地跟随其所属壳体移动，不再出现“半个圆角”。中段实体布尔检查确认：四个圆角的总缺料体积均为 `0.0 mm³`，且每个圆角由单一壳体独立覆盖，曲面上不存在上下壳分割。详见 [圆角接缝局部图](../previews/enclosure/rounded-corner-seam-detail.png)。

## 4. 四孔夹紧和安装顺序

四根轴完全读取主板现有四孔，不增加壳体安装孔：

| 孔 | X / mm | Y / mm |
| --- | ---: | ---: |
| 07/06 | +45.387 | +48.561 |
| 07/04 | -44.982 | +48.430 |
| 05/06 | +44.895 | -49.020 |
| 05/04 | -45.107 | -48.959 |

典型夹紧链为：

```text
底部紧固件 → 下壳套柱 → PCB 底面 → PCB → 上壳柱 → 上壳顶面
```

安装顺序：

1. 上壳外顶面朝下放置，内部向上。
2. 主板沿 `+Z` 放到四个上壳柱的平端面；没有打印结构伸入 PCB 孔。
3. 先让下壳中两颗对角螺钉略微伸出套柱，螺钉杆进入原 PCB 孔完成临时对中，再沿 `+Z` 合上下壳。
4. 四颗螺钉全部松起牙、六段接缝闭合后，再从底面均匀锁紧。

审阅几何暂用 `Ø6.4 mm` 平端柱、`Ø3.4 mm` 下壳通孔以及 `Ø2.5 mm` 上壳导孔。旧图中的 `Ø3.0 mm` 定位鼻已删除：它围绕 `Ø2.5 mm` 导孔时径向壁厚只有 `0.25 mm`，不适合打印，也没有必要。M3 仅由 `Ø3.2 mm` PCB 孔推断，螺钉头、热熔螺母或自攻形式尚未决定。四根柱与当前接口、散热组件和底面避让体均无碰撞。详见 [四孔夹紧剖面](../previews/enclosure/four-hole-clamp-section.png)。

## 5. 开孔覆盖审计

覆盖检查比较的是已审阅面板孔与有依据的接口功能鼻端/风道二维正投影，未增加打印余量。正值表示名义最小余量；0 表示按要求精确贴合；缺少真实前端轮廓时标为“不计算”，不再拿通用代理制造假冲突。

| 面 | 开孔 | 最小名义余量 / mm | 结果 | 解释 |
| --- | --- | ---: | --- | --- |
| 04 | DC | +0.200 | 通过 | Ø5.9 孔覆盖 Ø5.5 鼻端 |
| 04 | HDMI 1 | — | 不计算 | 保留已确认的 16.5 × 5.8 原壳六边形孔；真实连接器前端轮廓尚未建模 |
| 04 | 耳机 | +0.200 | 条件通过 | 代理被覆盖，但 Ø5.4 孔仍待实物确认 |
| 04 | RJ45 | 0.000 | 精确边界 | 当前鼻端顶边与 15 × 10 主窗相切；底部另有 4.5 × 1 relief |
| 04 | 叠层双 USB | +1.000 | 通过 | 同一 14 × 14.5 孔覆盖上下两个 USB |
| 04 | HDMI 3 | — | 不计算 | 保留已确认的 16.5 × 5.8 原壳六边形孔；真实连接器前端轮廓尚未建模 |
| 06 | 靠 05 USB | +0.400 | 通过 | 12.8 × 5.5 水平孔覆盖当前鼻端 |
| 06 | 靠 07 USB | +0.400 | 通过 | 12.8 × 5.5 水平孔覆盖当前鼻端 |
| 06 | 电源按钮 | +0.100 | 条件通过 | Ø9.4 孔覆盖实测 Ø9.2 原按钮穿孔段；板载触点退在内墙后，按钮行程待测 |
| 顶面 | 风扇进气 | 0.000 | 精确边界 | Ø33.5 对 Ø33.5，不增加风扇避让 |
| 04 | 鳍片出风 | 0.000 | 功能边界 | 84 × 7.4 连续无阻挡包络；最终格栅分段尚未设计 |

详见 [全部开孔覆盖图](../previews/enclosure/aperture-coverage-review.png)和机器报告 [enclosure-aperture-coverage.json](./enclosure-aperture-coverage.json)。

两个 HDMI 只画权威的六边形面板孔，不再绘制主板模型中的 `14 × 4.8 mm` 通用圆角矩形鼻端，也不报告假性的红色失败。该圆角矩形只可作为主板隐藏接口体积的临时外观占位，不能用于面板孔覆盖。确认真实 HDMI 金属口轮廓前，覆盖状态保持“不计算”，并且不修改六边形孔。

## 6. 本轮需要审阅的项目

1. 是否确认“上壳=顶+06+05，下壳=底+04+07”的对角三面壳。
2. 是否接受一条六段闭合缝；两条跨壳竖缝位于直边切点，圆角曲面不再分割。
3. 原壳 04–06 内跨距 `103.0 mm` 与侧壁 `1.8 mm` 已进入参数源；04/06 暂按接口突出量分配 `2.0/1.0 mm`，05/07 保持各 `0.20 mm`。原壳 05–07 的 `110.5 mm` 不作为本版尺寸依据。PCB 由原四孔/螺柱主要定位；仍需物理确认 provisional R4。
4. 是否接受四孔夹紧链的方向；紧固件头型和螺纹形式仍需选择。
5. 04 鳍片区域是保留 `84 × 7.4 mm` 连续功能包络，还是下一步按原壳外观设计格栅，但必须证明不阻挡出风。
6. 是否接受两个 HDMI 在本阶段保持“六边形孔已确认、真实连接器前端未建模、覆盖不计算”。

## 7. 文件和复现

- 唯一参数源：[n305_enclosure_structure.py](../src/n305_enclosure_structure.py)
- 审图生成器：[build_enclosure_structure_review.py](../scripts/build_enclosure_structure_review.py)
- 圆角接缝局部图：[rounded-corner-seam-detail.png](../previews/enclosure/rounded-corner-seam-detail.png)
- 机器结构定义：[enclosure-structure.json](./enclosure-structure.json)
- 覆盖检查：[enclosure-aperture-coverage.json](./enclosure-aperture-coverage.json)
- 内部验证：[enclosure-structure-validation.json](./enclosure-structure-validation.json)
- V2 上下壳、装配文件及 provisional 参数：[exports/enclosure/v2-prototype/README.md](../exports/enclosure/v2-prototype/README.md)
- V2 CAD 回读与网格验证：[validation.json](../exports/enclosure/v2-prototype/validation.json)
- V2 实体预览：[v2-prototype-parts.png](../previews/enclosure/v2-prototype-parts.png)
- 已批准并进入 V2 的内侧加强筋：[enclosure-reinforcement-review.md](./enclosure-reinforcement-review.md)
- 加强筋平面图：[reinforcement-inner-plan.png](../previews/enclosure/reinforcement-inner-plan.png)
- 加强筋碰撞检查图：[reinforcement-collision-check.png](../previews/enclosure/reinforcement-collision-check.png)

生成命令：

```bash
PYTHONDONTWRITEBYTECODE=1 PYTHONPATH=src .venv/bin/python scripts/build_enclosure_structure_review.py
PYTHONDONTWRITEBYTECODE=1 PYTHONPATH=src .venv/bin/python scripts/build_enclosure_reinforcement_review.py
PYTHONDONTWRITEBYTECODE=1 PYTHONPATH=src .venv/bin/python scripts/build_v2_prototype_enclosure.py
```

前两个脚本重建结构审图、加强筋审图与报告；第三个脚本读取同一参数源，把包含已批准加强筋的 V2 试装版写入 `exports/enclosure/v2-prototype/`，并生成伴随说明、清单和验证结果。单独运行加强筋审图脚本不会写 CAD；修改参数后必须再运行第三个脚本，不能把审图 PNG 当成已经更新 STEP/STL 的证据。

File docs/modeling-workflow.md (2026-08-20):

# 照片到 CAD 的固定流程

更新日期：2026-08-20

本流程解决本项目此前反复出现的根本问题：把照片中的透视、局部像素比例或视觉间距误当作机械坐标，导致参考图看似合理但无法可靠生成 STL。

## 数据链

```text
用户实测 / 卡尺读数
          │
          ├── 决定标称毫米尺寸和 PCB 包络
          │
PCB 对齐标定 ── 决定统一 Y/Z 中心
          │
原壳照片 ────── 只决定接口顺序和特殊轮廓
          │
          ▼
带 PCB 边界的正投影审图 + 机器可读参数
          │
          ▼ 用户确认
参数化 CAD → STEP/STL → 几何验证
```

照片局部网格属于证据层，正投影参考属于机械层，两者不得合并为同一坐标系。

## 每次建模前的检查清单

1. 当前物体属于照片证据、面板孔、主板实体、避让体还是外壳实体？
2. 每个尺寸的来源是用户实测、标尺照片、PCB 对齐标定还是推断？
3. 是否已经明确 PCB 原点、轴方向、观察方向和镜像关系？
4. 审图是否使用单一毫米比例并显示 PCB 边界？
5. 非标准轮廓是否来自原壳，而不是套用接口标准外形？
6. CAD 是否直接读取参数文件，而不是读取 PNG 像素？
7. 接触件是否真的接触，组合件是否存在完整装配/承力路径？
8. 是否只生成了用户已经批准进入三维阶段的对象？
9. 是否把 PCB 总体外接矩形误当成局部真实边界？遇到缺口、台阶或接口间内缩时，必须从同一正投影照片建立局部轮廓层级。
10. 面板位置是否由该面的最外侧实体约束件决定？不得用更矮或更内缩的开关触点替代 USB/接口肩部作为墙面基准。
11. 总跨距与设计余量是否分开记录？原壳侧壁实测厚 `1.8 mm`、04–06 内跨距约 `103.0 mm`；原壳 05–07 约 `110.5 mm` 包含无需复制的额外留空，当前设计仍使用 05/07 各 `0.20 mm` 试装余量。

## 当前数据入口

- 面板开孔机械数据：[n305_panel_reference.py](../src/n305_panel_reference.py)
- 面板开孔 JSON：[panel-apertures.json](./panel-apertures.json)
- 原壳照片像素证据：[n305_photo_reference.py](../src/n305_photo_reference.py)
- 照片标定记录：[photo-calibration.md](./photo-calibration.md)
- 主板元件面轮廓标定：[component-calibration.json](./component-calibration.json)
- 当前审阅基准：[v0.2-reference-review.md](./v0.2-reference-review.md)

## 审图最低内容

正投影参考图必须同时包含：

- PCB 实际边界和厚度；
- 统一毫米比例或可验证的尺寸链；
- 观察方向及相邻的 04/05/06/07 面；
- 每个孔的中心 Y/Z；
- 宽、高、直径、圆角和附加 relief；
- 实测、标定和 provisional 状态；
- “未加入打印余量”或已加入何种加工余量的明确说明。

## 三维验证最低内容

- PCB X/Y/Z 包络与四个安装孔；
- 接口和开关是否位于正确边与正确中心；
- 裸组件最高、最低 Z 和总厚度；
- 风扇、冷板、托板、热桥、鳍片之间是否存在连续接触；
- 面板开孔与接口功能区域的覆盖检查；
- 物理实体与 clearance/keepout 是否分开；
- STEP/STL/JSON/PNG 清单是否与文档一致。

## 可复用提示词

下面的提示词用于继续本项目或处理新的表面；方括号内容按任务替换：

> 处理 `[对象/表面]` 时必须遵守仓库 `AGENTS.md`。先读取现有参数、照片索引和审阅记录，再输出一张“数据来源表”，逐项区分：用户实测、卡尺读数、PCB 对齐标定、照片轮廓证据、provisional 推断。使用唯一坐标系 `+X=06, -X=04, +Y=07, -Y=05, +Z=风扇面, PCB底面Z=0`。01/02 卡尺图只确认 PCB 的 `100.0 × 105.5 mm` 平面，不把总宽差值对称平分成接口突出量；接口突出必须逐面、逐件记录，04 鳍片与接口不得共用前沿。照片只取接口语义和特殊轮廓，不把透视斜度、照片间距、不同 Z 高度造成的视差或局部网格当作全局机械位置。先生成统一毫米比例、带 PCB 边界、观察方向、中心 Y/Z、尺寸和来源的正投影审图；PNG 仅供审核，机器参数必须单独保存。外壳 04/06 应是各自完整、带贯通开孔的连续平面侧壁，不承担 PCB 贴边定位；面板位置应由最外侧真实接口而非内缩开关决定。原壳 `1.8 mm` 侧壁和约 `103.0 mm` 的 04–06 内跨距作为实测约束；原壳 05–07 的 `110.5 mm` 额外留空不进入当前紧凑设计。PCB 主要由原四孔和螺柱定位。只有我明确确认的对象才能进入 STEP/STL。三维 CAD 直接读取毫米参数，物理实体、面板孔、插头通道和 keepout 分开。组合件必须有真实接触/装配路径。导出后检查 PCB 包络、四孔、Z 包络、逐件接口突出、鳍片齐边、接口顺序和方向、孔对接口覆盖、连续墙体、接触链、输出文件清单，并明确列出仍属 provisional 的尺寸。未经批准不要生成外壳，也不要复用已撤销的旧 STL/STEP。

执行时必须给出以下四项，而不是只给一张看起来合理的图：

1. 采用的数据与来源；
2. 可审阅正投影或三维预览；
3. 参数源、生成命令和输出路径；
4. 自动校验结果与待实物确认项。

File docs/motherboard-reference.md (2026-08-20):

# N305 主板三维参考

更新日期：2026-08-20

状态：**PCB/主板参考已重建；外壳 V2 试装版已从独立结构参数源生成。**

## 模型用途

该模型为外壳设计提供统一的 PCB 基准、接口实体、安装孔、Z 向包络和散热接触关系。它不是主板厂商 CAD，也不用于生产或维修主板本身。

物理实体与避让体分开导出：

```text
主板物理参考
├── PCB + 四个安装孔
├── 04/06 接口实体 + 板载开关
└── 散热组件
    ├── 冷板 / 支撑
    ├── 风扇托板
    ├── 鼓风机壳与转子示意
    ├── 热桥
    └── 鳍片

独立避让参考
├── 散热组件包络
├── 底面器件包络
└── 四孔装配轴线
```

## 已作为机械基准的数据

| 项目 | 当前值 |
| --- | ---: |
| PCB | 100.0 × 105.5 × 1.5 mm |
| PCB 底面 / 顶面 | Z=0 / Z=1.5 mm |
| PCB 底面至最低器件 | 10.25 mm |
| PCB 顶面至风扇最高面 | 13.8 mm |
| 裸组件实测总厚度 | 约 25.6 mm |
| 安装孔直径 | Ø3.2 mm |
| 风扇中心 | X=-0.20, Y=-3.45 mm |
| 风扇进气口 | Ø33.5 mm |
| 04 双 USB 相对 PCB 04 边突出 | 约 2.0 mm（用户粗测，当前最大值） |
| 06 两个 USB 相对 PCB 06 边突出 | 约 1.0 mm（用户粗测） |
| 04 鳍片相对 PCB 04 边突出 | 0.0 mm（与 PCB 边齐平） |

四个孔没有按对称关系重猜，而是逐孔保存：

| 角位 | X / mm | Y / mm |
| --- | ---: | ---: |
| 07/06 | +45.387 | +48.561 |
| 07/04 | -44.982 | +48.430 |
| 05/06 | +44.895 | -49.020 |
| 05/04 | -45.107 | -48.959 |

照片标定带来的孔位不确定度记为 ±0.35 mm。04/06 接口中心直接读取 [n305_panel_reference.py](../src/n305_panel_reference.py)，与已审阅的正投影图共用同一数据源。

01/02 卡尺照片确认的是 PCB 平面 `100.0 × 105.5 mm`，卡爪没有测量接口鼻端，因此不存在可据此建立的 `103.4 mm` 对称接口包络。接口前沿必须逐件保存：04 叠层双 USB 当前到 `X=-52.0 mm`，06 两个 USB 到 `X=+51.0 mm`，04 鳍片外沿与 `X=-50.0 mm` PCB 边齐平。04 的 DC、HDMI、耳机和 RJ45 只知道“略凸”，当前使用 `1.0 mm` 的显式 provisional 外观代理，受 04 面约 `2.0 mm` 最大粗测值约束，不能当作逐件实测。

板载开关不能从 `X=50` 的外接矩形边推导。03俯视图显示开关触点比06 USB 前沿约内退 `1.2 mm`，其相邻 PCB 外形还有局部台阶；06侧视图同时显示 USB 是更高的墙面约束件。当前照片代理把 USB 前沿放在 `X=51.0 mm`、开关触点放在 `X≈49.8 mm`，平面不确定度暂记 `±0.4 mm`。开关不参与接口总包络，也不应作为面板孔对板载实体的穿墙覆盖目标；Ø9.4 孔应覆盖用户实测 Ø9.2 的原按钮穿孔段。

PCB STEP/STL 目前仍使用完整 `100 × 105.5 mm` 外包络作为保守碰撞体，不从单张照片虚构局部台阶的精确切口。局部内缩已用于开关/墙面关系，但尚未作为已测 PCB 轮廓切入实体；这会高估而不会低估墙体碰撞风险。

风扇外壳使用 [01 照片 PCB 对齐轮廓](../previews/calibration/01-blower-profile-trace.png)，当前包围范围约为 `X=-29.2…+25.4 mm、Y=-34.0…+19.8 mm`，保留朝 04 的出风蜗舌以及偏置进风口。叶轮改为 32 片后弯叶片，不再使用三根径向杆示意。机器转换记录见 [component-calibration.json](./component-calibration.json)。

01 顶视照片中可见的双孔长条不能用于确定 Z 高度；05 侧视照片也不支持它位于风扇上表面。旧模型中悬在风扇顶部的长条已删除，不再计入实体或避让包络。若以后需要还原该零件，必须先从侧视证据确定它与 PCB 的安装关系，不能再根据顶视遮挡关系猜高度。

## 散热组件不再悬空

模型显式建立以下连续路径：

```text
PCB → 冷板/支撑 → 风扇托板 → 热桥 → 鳍片
                       └──────→ 鼓风机壳
```

[接触链侧视图](../previews/reference/cooling-contact-path.png)用于视觉复核；构建脚本还会检查相邻件零距离且存在有效接触/交叠体积。数值结果见 [validation.json](../exports/reference/validation.json)。

这里的“接触”是壳体设计所需的拓扑和包络约束，不表示已经还原真实导热材料、螺钉、弹簧压力或内部热管截面。

## 精度分层

已测量或 PCB 对齐：PCB 总体外接包络和厚度、总 Z 包络、四孔、接口中心、板载开关 Y/Z 中心、风扇中心/进气口以及已确认的面板开孔尺寸。

照片重建或保守近似：PCB R4 圆角、06开关相对 USB 的 `1.2 mm` 平面内退和相邻 PCB 台阶、04 非双 USB 接口的 `1.0 mm` 前伸代理、连接器隐藏壳体的深度/局部外形、冷板支撑和热桥细节、风扇蜗壳折线间的曲率、叶片厚度/曲率、鳍片厚度/节距、底面器件块状避让体。双孔长条因缺少可靠的 Z 向证据而不建模。上述近似在源码和验证 JSON 中不得表述成用户实测值。

尤其要区分：面板孔的尺寸不等于板载接口实体的鼻端尺寸；未来外壳 CAD 应直接读取面板参数，并用接口实体/插头通道做覆盖校验。

## 当前输出

- [风扇面三维预览](../previews/reference/motherboard-isometric.png)
- [风扇面正投影三维参考](../previews/reference/motherboard-plan.png)
- [底面及接口预览](../previews/reference/motherboard-bottom.png)
- [物理 STEP/STL](../exports/reference/physical/)
- [避让 STEP/STL](../exports/reference/clearances/)
- [完整验证 JSON](../exports/reference/validation.json)

## 本轮审阅重点

1. 四孔和 PCB 朝向是否正确。
2. 04 的 DC、HDMI 1、耳机、RJ45、双层 USB、HDMI 3 是否按 `+Y→-Y` 排列。
3. 06 两个 USB 是否水平并共享同一 Z 中心；开关是否位于偏 07 一侧。
4. 散热器是否在 04 一侧，风扇中心和鳍片跨度是否符合照片。
5. 底面保守避让体是否需要进一步拆分或缩小。

确认这些内容后，才进入外壳开孔覆盖与装配面的三维阶段。

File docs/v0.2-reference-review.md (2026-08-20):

# V0.2 当前审阅基准

更新日期：2026-08-20

状态：**已恢复 PCB 边界的 04/06 正投影开孔审阅基准，重建主板三维参考，并基于外壳结构定义生成 V2 试装版 STEP/STL。**

## 1. 仍然有效的用户约束

- 正对风扇面时：鳍片在下，左边 07，上方 06，右边 05，下方 04。
- 顶板、底板精确为 1.2 mm，不额外增加风扇避让高度。
- 外壳最终为上壳、下壳两件，原机按钮复用；不增加独立外壳螺丝位。
- 主板先放入上壳，再安装下壳；最终利用主板原有四孔建立夹紧链。
- 为便于制造，04/06 各保留一整面连续实体墙，只切除已审阅贯通孔和必要风道；两面不贴合定位 PCB。原壳实测 04–06 内距约 103.0 mm、侧壁厚 1.8 mm；当前 X 向单侧分配仍按接口突出量标为 provisional。原壳 05–07 约 110.5 mm 的内距属于不需要复制的额外留空，当前 05/07 仍各留 0.20 mm 紧凑试装余量。
- 01/02 卡尺图只确认 PCB `100.0 × 105.5 mm`，接口突出量逐面、逐件记录，不构造对称总包络。
- 旧连续卡槽、绕壳舌槽和额外四个壳体螺丝位不采用。

这些是功能/装配约束，不等于已经建立了可生成的三维几何。

当前面板坐标统一为：PCB 04/06 边长 `105.5 mm`，PCB 厚 `1.5 mm`；`Y=0` 位于边中心，`+Y` 指向 07，`-Y` 指向 05；`Z=0` 是 PCB 底面，`+Z` 指向风扇面。
机器可读的当前数据为 [panel-apertures.json](./panel-apertures.json)，源定义为 [n305_panel_reference.py](../src/n305_panel_reference.py)。

## 2. 当前 04 开孔

| 开孔 | 中心 Y / mm | 中心 Z / mm | 尺寸 / mm |
| --- | ---: | ---: | ---: |
| DC | +39.83 | -4.33 | Ø5.9 |
| HDMI 1 | +23.75 | -5.02 | 16.5 × 5.8；顶边 10.7；倒角高 1.9 |
| 耳机孔 | +23.75 | +3.57 | 约 Ø5.4，待实物确认 |
| RJ45 主窗 | +3.75 | -3.55 | 15.0 × 10.0，R0.6 |
| RJ45 底部 relief | +3.75 | 主窗下方 | 额外 4.5 × 1.0 |
| 叠层双 USB | -14.25 | -3.47 | 14.0 × 14.5，R0.7 |
| HDMI 3 | -36.08 | -5.27 | 16.5 × 5.8；顶边 10.7；倒角高 1.9 |

两个必须保持的语义：

1. 叠层接口是上下两个 USB，不是 USB + HDMI。
2. RJ45 的 15 × 10 mm 是完整主窗；4.5 × 1 mm relief 在主窗之外，所以整体包围高度是 11 mm。

审图文件：

- [原壳照片网格叠图（轮廓证据）](../previews/calibration/original-case-04-1mm-grid.png)
- [PCB 基准正投影参考](../previews/reference/04-interface-reference.png)
- [详细像素记录](./photo-calibration.md)

## 3. 当前 06 开孔

| 开孔 | 中心 Y / mm | 中心 Z / mm | 尺寸 / mm |
| --- | ---: | ---: | ---: |
| 靠 05 的 USB | -15.25 | -3.14 | 12.8 × 5.5，R0.7 |
| 靠 07 的 USB | +4.75 | -3.14 | 12.8 × 5.5，R0.7 |
| 电源开关孔 | +29.50 | -4.20 | Ø9.4 |

06 图以 PCB `105.5 × 1.5 mm` 边界为基准。两个相同 USB 使用水平正投影轮廓并共享 `Z=-3.14 mm`，中心 Y 为 `-15.25/+4.75 mm`；按钮孔中心为 `Y=+29.50 mm`、`Z=-4.20 mm`。照片中的像素高差判定为透视误差，不再传入机械模型。

审图文件：

- [06 原壳照片网格叠图](../previews/calibration/original-case-06-1mm-grid.png)
- [06 面板正投影 CAD 参考](../previews/reference/06-interface-reference.png)

## 4. 已撤销的结果

以下内容不再作为 V0.2 依据，相关生成物已删除：

- 未与 PCB 基准对齐的主板侧照手工坐标框和网格。
- 从 03、04、06 不同透视照片直接拼接的像素坐标。
- 旧的照片透视版 04/06 开孔参考图。
- 旧主板、散热包络、孔位、面板开孔和外壳 STEP/STL。
- 与这些三维文件对应的预览图和验证 JSON。

这些项目所指的是旧版输出，不包括 2026-08-20 按新数据链生成的 `exports/reference/`。

## 5. 当前主板三维参考

当前主板模型从 [n305_mainboard_reference.py](../src/n305_mainboard_reference.py) 重新生成，说明见 [motherboard-reference.md](./motherboard-reference.md)。它包含 PCB、逐孔安装孔、接口实体、板载开关、连续连接的散热组件以及独立避让体。主板参考包中的 `enclosure_geometry_generated=false` 只表示该脚本不会把外壳混入主板导出；V2 外壳由独立脚本和目录生成。

接口实体的中心使用本页已审阅坐标。04 双 USB 突出约 2.0 mm、06 USB 突出约 1.0 mm按用户粗测独立保存，04 鳍片与 PCB 边齐平；04 其余接口前伸仍是显式 provisional 代理。未实测的连接器隐藏壳体和散热局部细节均按照片近似或保守包络处理，不覆盖本页的面板开孔尺寸。

## 6. 进入外壳三维前必须完成

1. 审阅当前主板三维参考的四孔、接口实体、散热布局和避让体。
2. 对每个接口执行“接口实体/插头通道 vs 面板开孔”的覆盖检查。
3. 明确每个面/边的装配结合方式和主板四孔夹紧链。
4. 上述结构结果已经进入 V2 试装输出；实物试装确认 provisional 参数后，才生成最终制造版。

结构定义、四孔夹紧剖面和开孔覆盖见 [enclosure-structure-review.md](./enclosure-structure-review.md)；V2 文件及全部试制参数见 [V2 伴随说明](../exports/enclosure/v2-prototype/README.md)。

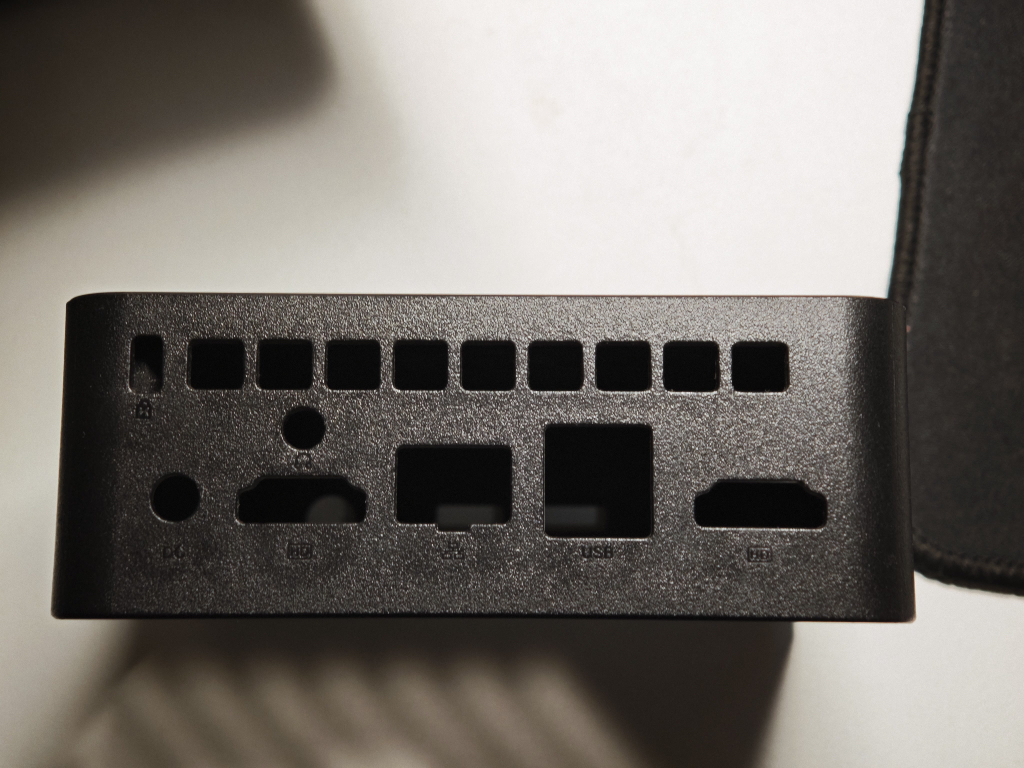
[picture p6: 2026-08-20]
pics/机箱盒子04.jpg

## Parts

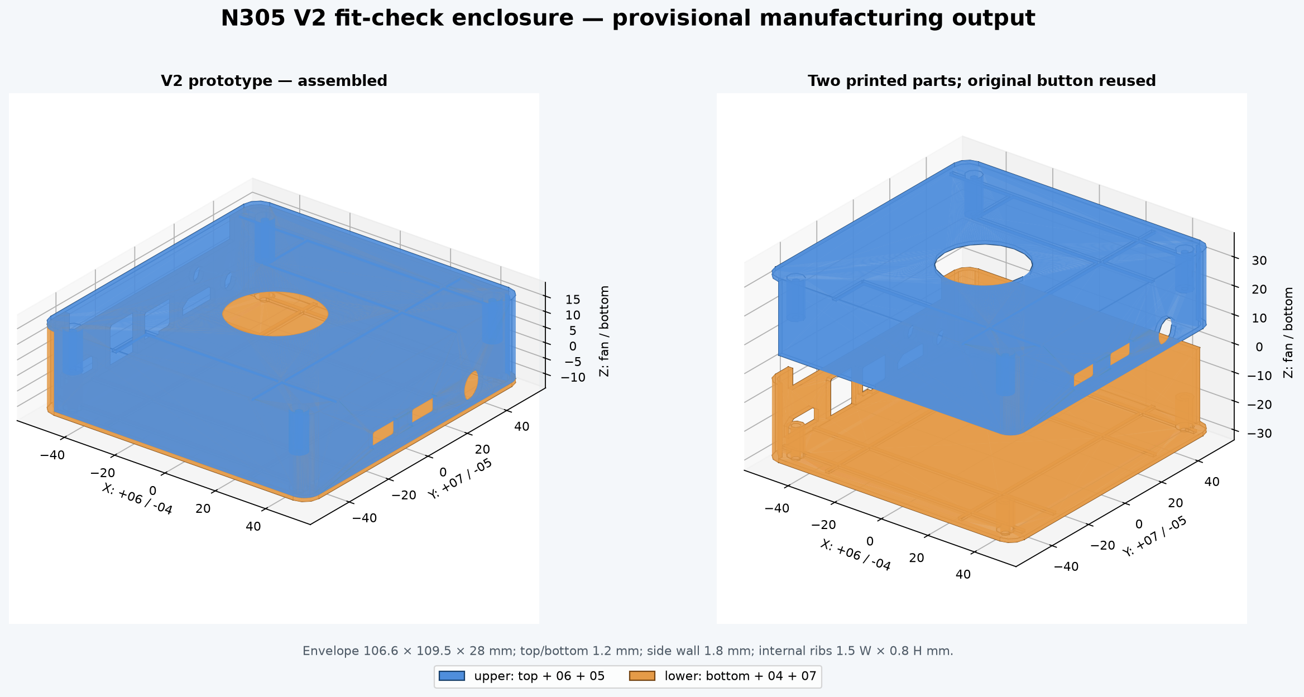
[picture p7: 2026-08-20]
previews/enclosure/v2-prototype-parts.png

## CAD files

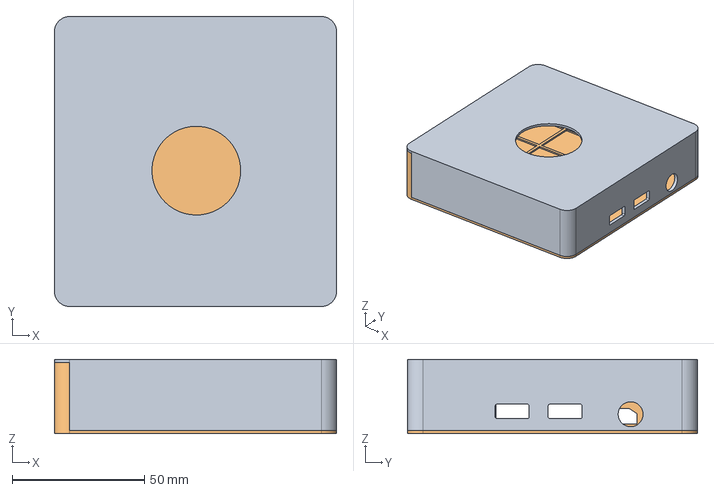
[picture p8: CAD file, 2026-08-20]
exports/enclosure/v2-prototype/n305_v2_enclosure_assembly.step
106.6 x 109.5 x 28.0 mm

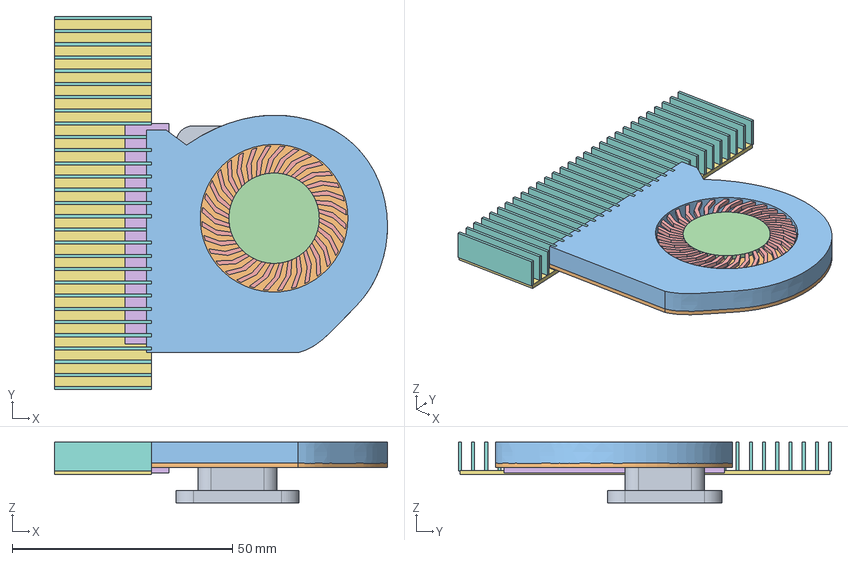
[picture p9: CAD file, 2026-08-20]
exports/reference/physical/n305_cooling_assembly.step
75.5 x 84.7 x 13.8 mm

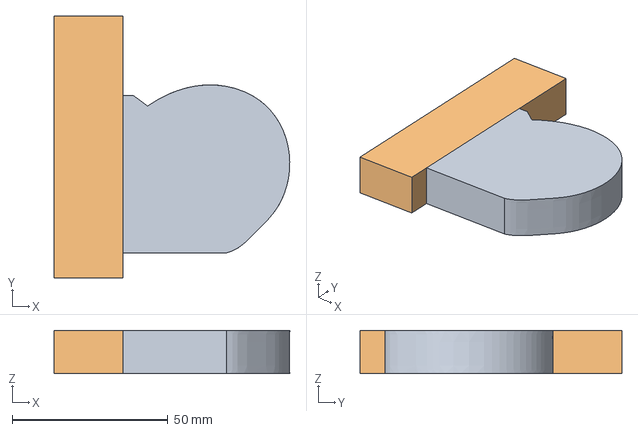
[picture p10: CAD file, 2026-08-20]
exports/reference/clearances/n305_cooling_keepout.step
75.5 x 84.0 x 13.8 mm

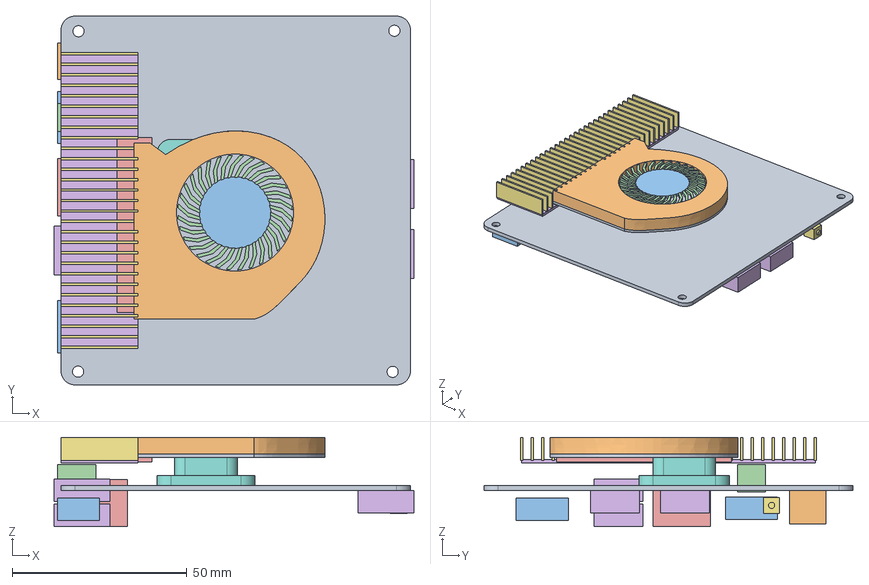
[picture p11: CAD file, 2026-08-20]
exports/reference/physical/n305_motherboard_reference.step
103.0 x 105.5 x 25.6 mm

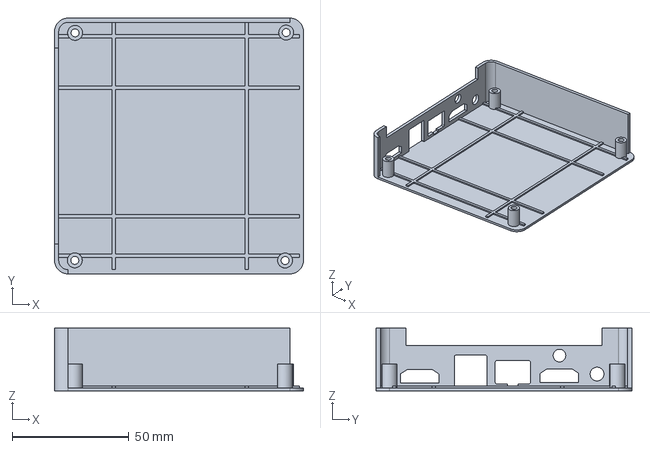
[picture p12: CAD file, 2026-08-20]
exports/enclosure/v2-prototype/n305_v2_lower_shell.step
106.6 x 109.5 x 26.8 mm

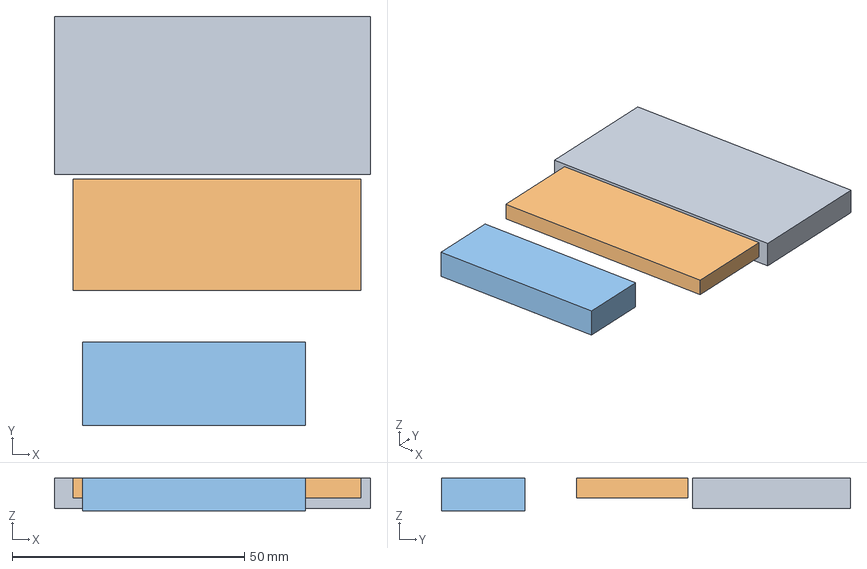
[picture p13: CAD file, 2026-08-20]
exports/reference/clearances/n305_underside_keepouts.step
68.0 x 88.0 x 7.00 mm

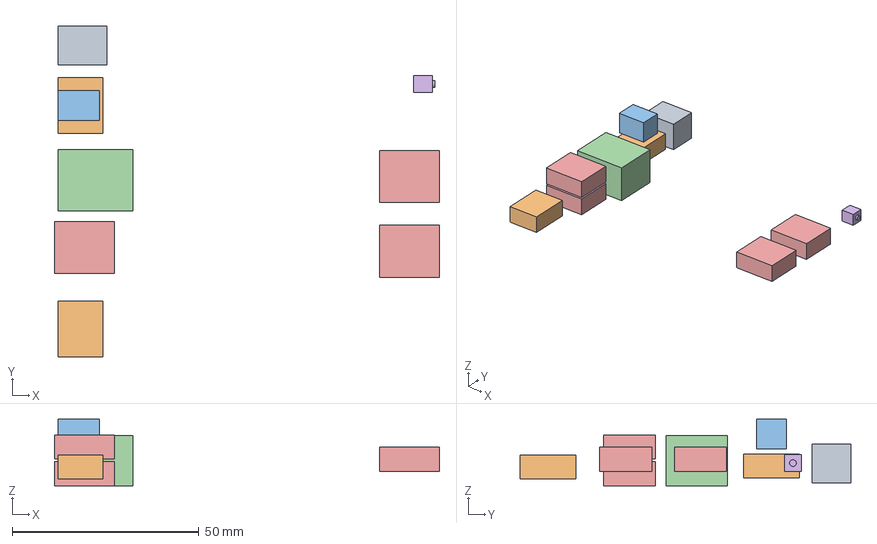
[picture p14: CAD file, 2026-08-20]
exports/reference/physical/n305_connectors_and_switch.step
103.0 x 88.7 x 17.9 mm

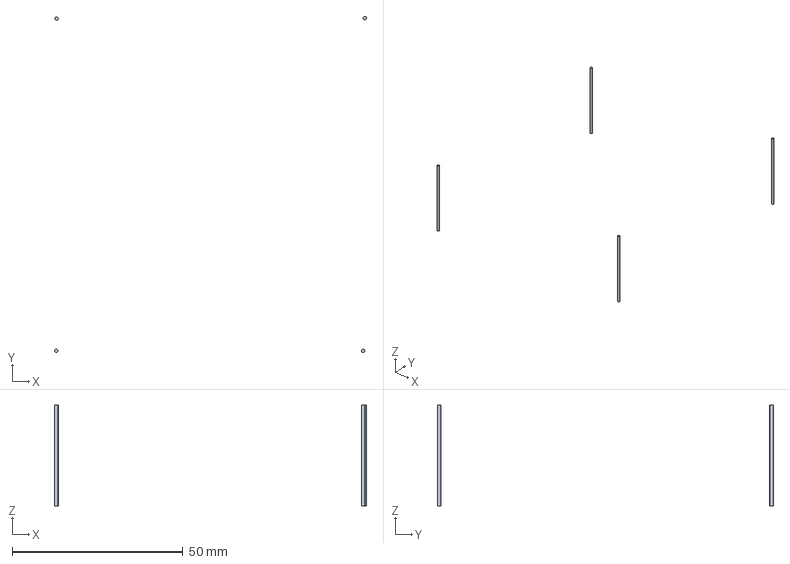
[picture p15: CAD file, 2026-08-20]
exports/reference/clearances/n305_mount_axes.step
91.5 x 98.6 x 29.6 mm

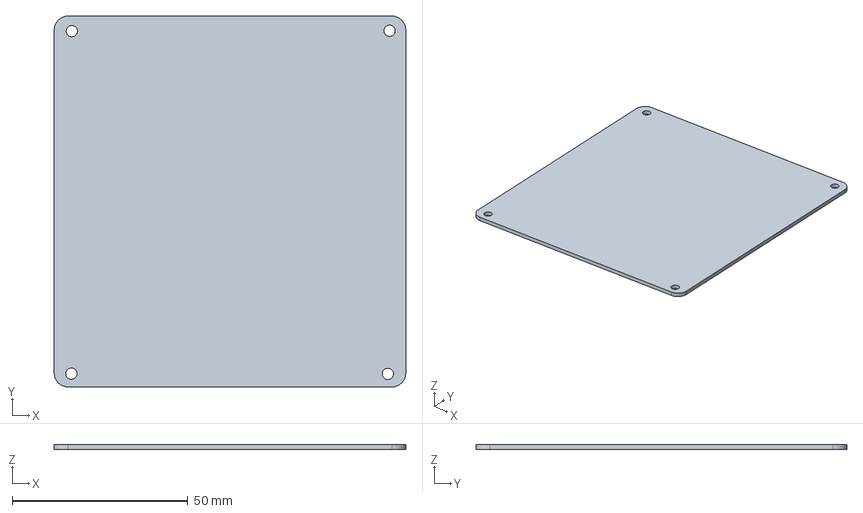
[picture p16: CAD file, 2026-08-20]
exports/reference/physical/n305_pcb.step
100.0 x 105.5 x 1.50 mm

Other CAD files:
exports/enclosure/v2-prototype/n305_v2_upper_shell.step
exports/enclosure/v2-prototype/n305_v2_enclosure_assembly.stl
exports/enclosure/v2-prototype/n305_v2_lower_shell.stl
exports/enclosure/v2-prototype/n305_v2_upper_shell.stl
exports/reference/clearances/n305_cooling_keepout.stl
exports/reference/clearances/n305_mount_axes.stl
exports/reference/clearances/n305_underside_keepouts.stl
exports/reference/physical/n305_connectors_and_switch.stl
exports/reference/physical/n305_cooling_assembly.stl
exports/reference/physical/n305_motherboard_reference.stl
exports/reference/physical/n305_pcb.stl

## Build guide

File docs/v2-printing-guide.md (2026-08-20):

# N305 V2 外壳打印、下单与试装指南

更新日期：2026-08-21

适用版本：`v2-prototype-2026-08-21-ribbed`

状态：试装指南，不代表当前 CAD 已达到量产状态。

## 1. 先给结论

本项目当前最稳妥的制造路线是：

1. 先用 **FDM + PETG** 低成本打印一套完整上下壳，验证主板能否放入、四孔是否同轴、接口是否能插拔、原按钮是否会误压开关。
2. 把实测结果写回 CAD，不要只在切片软件里整体缩放或临时磨掉干涉处。
3. 尺寸收敛后，再用国内工业打印平台下单 **MJF/SLS + PA12 或 PA12S 尼龙**，作为长期使用的功能样机。

如果不方便使用 FDM，也可以直接下单 PA12，但必须把本页第 5 节列出的薄壁、间隙和未确认项交给平台工程师审核。当前版本是试装版，一次下单成功不等于所有 provisional 参数已经得到验证。

## 2. 应该提交哪些文件

打印时只提交两个独立零件：

- [上壳 STL](../exports/enclosure/v2-prototype/n305_v2_upper_shell.stl)
- [下壳 STL](../exports/enclosure/v2-prototype/n305_v2_lower_shell.stl)

STEP 文件用于修改、工程审核或平台要求实体模型时提供：

- [上壳 STEP](../exports/enclosure/v2-prototype/n305_v2_upper_shell.step)
- [下壳 STEP](../exports/enclosure/v2-prototype/n305_v2_lower_shell.step)

不要打印：

- `n305_v2_enclosure_assembly.stl`
- `n305_v2_enclosure_assembly.step`

装配文件包含上下壳闭合位置，只用于总体检查。嘉立创的当前下单规则也要求一个文件不要包含多个模型或成套装配体，并明确支持 STL、STP、STEP、OBJ 和 3MF；其官方建议生产上传 STL。[嘉立创下单须知](https://www.jlc-3dp.cn/technicalColumnsDetails/40026.html)

上传后必须检查：

| 项目 | 正确结果 |
| --- | --- |
| 单位 | mm |
| 数量 | 上壳 1 件、下壳 1 件 |
| 每个零件的预览外包络 | 约 `106.6 × 109.5 × 26.8 mm` |
| 闭合后的总厚度 | `28.0 mm`，不是单件上传尺寸 |
| 自动缩放 | `100%` / `1.000` |
| 模型方向 | 方向变化不应改变尺寸；不得镜像 |

STL 本身是三角网格，通常不可靠地携带单位信息；看到平台预览尺寸不符时应停止下单，不能用“看起来差不多”判断。STEP 保留精确实体和单位，更适合作为 DFM 审核附件，但不要把同一个零件的 STEP 和 STL 当成两件商品重复下单。

完整参数、文件哈希和自动验证结果分别见 [manifest.json](../exports/enclosure/v2-prototype/manifest.json) 与 [validation.json](../exports/enclosure/v2-prototype/validation.json)。

> 本次重新生成前已经上传到平台的同名 STL 不会自动更新。新模型已融合 `1.5 × 0.8 mm` 内侧加强筋；已有订单或购物车必须删除旧文件并重新上传。新文件预览体积应约为：上壳 `24.13 cm³`、下壳 `23.02 cm³`；旧截图中的约 `23.66/22.31 cm³` 说明仍是无筋旧文件。

## 3. 材料和工艺怎么选

### 推荐的两阶段方案

| 用途 | 工艺和材料 | 结论 |
| --- | --- | --- |
| 第一次尺寸试装 | FDM PETG | 首选低成本方案；韧性和耐热性比 PLA 更适合通电前后的机壳试验，但孔和接口边缘精度依赖打印机标定 |
| 尺寸收敛后的功能样机 | MJF PA12S / PA12 | 首选外包方案；无需支撑、韧性较好，适合复杂外壳、螺柱和反复拆装 |
| 仅看外观或短时无电试装 | FDM PLA | 可以，但不建议作为通电长期使用外壳 |
| 有封闭腔体且已熟练调机 | FDM ABS / ASA | 可用，但当前约 107 × 110 mm 的大薄板更容易翘曲，不作为首次试打默认选项 |
| 整套外壳 SLA 普通/类 ABS 树脂 | 不推荐当前版本 | 大平板、细螺柱和螺钉夹紧对收缩、脆裂及耐热更敏感；当前 `1.2 mm` 板厚也低于嘉立创类 ABS40 的 `1.5 mm` 推荐壁厚 |
| 碳纤增强材料 | 暂不推荐 | 成本、喷嘴和表面磨蚀要求更高，试装阶段没有必要；含碳材料还不适合作为未评估的电子绝缘假设 |

嘉立创将树脂定位为高精细外观材料，将尼龙定位为功能件材料，并提示树脂存在收缩、受热变形风险。[嘉立创下单须知](https://www.jlc-3dp.cn/technicalColumnsDetails/40026.html) 其 PA12/PA12S 资料说明两者可采用 MJF/SLS 无支撑成型；PA12S 还给出约 `±0.25～0.3 mm` 的尺寸公差及 `1.0 mm` 最小壁厚能力。[PA12S 官方资料](https://www.jlc-3dp.cn/technicalColumnsDetails/60903.html) [PA12 官方资料](https://www.jlc-3dp.cn/technicalColumnsDetails/61261.html)

这些数值是服务商的工艺/材料声明，不是本项目的实物验收结果。尤其不能用材料页的“最小壁厚”代替本项目的大平板翘曲审核。

### 为什么不直接把 PLA 当成最终材料

PLA 适合快速、便宜地确认外形，但带风扇的小主机内部存在持续热源。材料供应商的公开数据也显示，常见 PETG 的热变形温度高于其基础 PLA 对照材料；实际结果仍随配方和打印条件变化。[Bambu PETG HF 官方数据](https://eu.store.bambulab.com/en-mt/products/petg-hf)

因此：PLA 只用于无电或短时尺寸确认；PETG 用于第一套完整试装；长期功能样机优先 PA12。任何材料若没有明确的阻燃等级，都不能因为“是工程塑料”就默认具有阻燃认证。

## 4. 国内平台建议

### 首选：嘉立创 3D 打印

适合希望在线上传、自动报价并由工程师审核的订单。本项目建议询价：

- 工艺：优先 `MJF`，其次 `SLS`
- 材料：优先 `PA12S`，没有时选择 `PA12`
- 数量：上壳 1、下壳 1
- 后处理：第一套不喷漆、不喷油、不做会增加尺寸的不透明涂层；染黑可等试装通过后再选
- 备注：要求审核基础 `1.2 mm` 平板、内侧 `1.5 mm` 宽 × `0.8 mm` 高加强筋、`1.8 mm` 侧壁、深孔清粉和整体翘曲

嘉立创网页和淘宝上传入口当前都支持 STL/STP/STEP 等格式；网站通用须知写的是壁厚通常应“大于 `1.2 mm`”，而 PA12S 专项资料写的是最小可做到 `1.0 mm`。当前顶板和底板的连续基础厚度精确为 `1.2 mm`，筋路处局部为 `2.0 mm`。加强筋降低了大平面柔度，但筋间区域仍处在壁厚边界，因此必须人工确认，不能只依赖自动报价通过。[官方下单须知](https://www.jlc-3dp.cn/technicalColumnsDetails/40026.html) [淘宝订单上传入口](https://www.jlc-3dp.cn/tbOrder) [PA12S 官方资料](https://www.jlc-3dp.cn/technicalColumnsDetails/60903.html)

#### 本次含筋版在嘉立创的上传记录

2026-08-21 将本目录当前两个 STL 重新上传至[嘉立创 3D 打印](https://www.jlc-3dp.cn/)后，页面显示如下。该记录同时是识别“平台是否仍缓存旧 STL”的核对基准：

| 文件 | 平台尺寸 | 体积 | 表面积 | 材料 / 颜色 | 数量 | 页面单价 |
| --- | ---: | ---: | ---: | --- | ---: | ---: |
| `n305_v2_lower_shell.stl` | `2.68 × 10.66 × 10.95 cm` | `23.02 cm³` | `347.4 cm²` | PA12 / 灰黑色 | 1 件样品 | `¥41.75` |
| `n305_v2_upper_shell.stl` | `2.68 × 10.66 × 10.95 cm` | `24.13 cm³` | `347.96 cm²` | PA12 / 灰黑色 | 1 件样品 | `¥43.76` |

两件页面单价相加为 `¥85.51`。这个数值只记录当次页面状态；不包含截图未显示的运费、税费、优惠、工程复核调价或交期变化，不能当作长期固定报价。

本次页面选择为：喷漆“不需要”、染色“不需要”、镶嵌螺母“不需要”。这与首套功能试装策略一致：避免涂层改变接口孔、按钮孔和接缝尺寸；当前 CAD 也没有按具体嵌件建立安装孔，因此不得让平台直接加装镶嵌螺母。

平台显示的三个尺寸按自身顺序排列，等价于模型约 `106.6 × 109.5 × 26.8 mm` 的外包络，并不表示模型被旋转或缩放错误。体积 `23.02/24.13 cm³` 与仓库验证值一致，说明这次读取的是已融合 `1.5 × 0.8 mm` 加强筋的新 STL；若仍显示旧截图中的约 `22.31/23.66 cm³`，应删除平台文件后重新上传。

### 备选比价：云工厂

云工厂官网当前列出 SLA、SLS、MJF、FDM 服务，支持 STEP、IGES、STL 等格式，并提供工程审核；可用它做第二份 PA12 报价或交叉确认薄壁可制造性。[云工厂官网](https://yungongchang.com/zh-cn/)

不要仅凭平台页面上的“典型精度”就认定本外壳一定能装。下单前应要求对方明确回复：

- 基础 `1.2 mm`、带 `1.5 × 0.8 mm` 稀疏筋的大平板是否接受，以及预期翘曲如何控制；
- `Ø2.5 mm` 深导孔能否完整成型和清粉；
- `Ø3.4 mm` 通孔、`Ø9.4 mm` 按钮孔的预期误差；
- 是否会未经确认自动加厚、缩放、封孔或修复网格；
- 能否对关键尺寸做出货测量，而不只是给材料的理论公差。

### 本地打印店、淘宝或个人 FDM 服务

可以承担第一套 PETG 试装，但只选择愿意说明打印机、喷嘴、材料品牌、层高和尺寸补偿的商家。若商家不能确认单位、方向和外包络尺寸，价格再低也不适合本项目。不要接受对整个模型进行统一缩放来“补收缩”，因为这会同时改变 PCB 孔距、接口孔和按钮孔。

## 5. 当前 V2 下单前必须知道的风险

自动验证已经确认 STEP/STL 可回读、上下壳均为单个有效实体、没有几何体积重叠，且已计算的开孔覆盖没有失败。但打印工艺会引入模型验证无法覆盖的误差：

| 风险 | 当前参数 | 为什么要关注 |
| --- | ---: | --- |
| 大面积薄板 | 顶、底基础各 `1.2 mm`；筋宽 `1.5 mm`、高 `0.8 mm` | 筋路处局部总厚度为 `2.0 mm`，变形风险低于无筋旧版，但筋间板面仍处在服务商壁厚边界，不能据此忽略翘曲审核 |
| 05/07 紧凑余量 | 每侧 `0.20 mm` | 小于或接近多数打印工艺的单件尺寸波动，实际可能紧配甚至干涉 |
| 上下壳接缝 | CAD 名义间隙 `0.0 mm` | 实物不会自动获得完美零缝；毛边、翘曲和孔位误差都会阻止闭合 |
| 04/06 内跨距 | `103.0 mm` | 由原壳内距和 USB 突出量建立，接口前沿接近墙体基准，不能靠强压装入 |
| 上柱导孔 | `Ø2.5 mm` | 目前只定义为 M3 级 provisional 方案，尚未确定攻丝、塑料自攻或嵌件 |
| 下柱通孔 | `Ø3.4 mm` | 没有螺钉头沉孔或沉头，螺钉头会露在底面 |
| 原按钮 | 穿墙部分 `Ø9.2 mm`，壳孔 `Ø9.4 mm` | 理论直径余量只有 `0.2 mm`；打印收缩、孔毛边都可能导致卡滞 |
| 按钮轴向关系 | 外墙面到开关触点约 `2.6～3.4 mm` | 来自照片和壁厚推导；原按钮隐藏顶杆长度、静止余量和有效行程仍未实测 |
| 两个 HDMI | 原壳六边形孔 | 真实连接器鼻端轮廓未测量，自动覆盖检查刻意标为“未计算” |

这意味着当前订单必须标记为“fit-check prototype”。如果 `05/07` 太紧、接缝无法闭合或按钮卡滞，应回到参数源增加独立制造补偿；不要在切片器里全局放大，也不要把打磨后的尺寸误认为 CAD 正确。

## 6. FDM PETG 切片起始参数

以下是 `0.4 mm` 喷嘴、常见 PETG 的保守起点，不是对所有打印机通用的固定配方。喷嘴温度、热床温度、流量和最大速度应从所用耗材厂商配置开始。

| 参数 | 起始建议 |
| --- | --- |
| 层高 | `0.20 mm`；`1.2 mm` 板正好形成 6 层 |
| 线宽 | 约 `0.42～0.45 mm` |
| 墙线 | 4 道；启用 Arachne/薄壁处理，并在切片预览里确认 `1.8 mm` 侧墙没有缺线 |
| 顶/底实心层 | 至少 6 层，确保 `1.2 mm` 板完整实心 |
| 填充 | `25～35%` gyroid；薄板和侧壁主要由实心层/墙线决定，盲目 100% 填充不能解决翘曲 |
| 外墙速度 | 先用 `30～50 mm/s` 的保守范围，细节和桥接处进一步减速 |
| 附着 | 清洁平台，使用 `8～12 mm` brim 或四角 mouse ears；先不用 raft |
| 象脚补偿 | 从已标定的机器配置开始；不要为了某一个孔临时全局缩放模型 |
| 支撑 | 默认关闭；只在切片桥接预览显示接口上沿失败时局部绘制，阻止支撑进入螺钉孔和按钮孔 |

`0.8 mm` 高加强筋在 `0.20 mm` 层高下应形成 4 个完整层。切片预览必须确认每一条筋都连续、与基础板融合，没有被薄壁过滤器删除；若切片器丢失筋路，应先修正线宽/薄壁设置，不能通过整体缩放模型补救。

摆放方向：

- 上壳：外顶面贴平台，内腔朝上。
- 下壳：外底面贴平台，内腔朝上。
- 不要竖起来打印整壳，也不要把两个壳套在一起打印。

这样可让四根柱沿 Z 方向生长，并用最大平面稳定零件。代价是外顶/底面会保留平台纹理，接口孔上沿则需要检查桥接质量。开启切片预览后逐层检查：风扇圆孔、按钮圆孔、USB/HDMI/RJ45 上沿、`Ø2.5/3.4 mm` 孔和圆角接缝不能被错误封闭。

## 7. MJF/SLS 下单备注模板

可把下面文字随订单提交给工程师：

> 两个独立电子设备外壳试装件，单位 mm，不允许缩放或镜像。上壳、下壳各 1 件，材料拟用 MJF PA12S/PA12。关键结构：顶底连续基础板 1.2 mm，内侧加强筋宽 1.5 mm、高 0.8 mm（筋路处局部总厚 2.0 mm），侧壁 1.8 mm，上柱 Ø6.4/导孔 Ø2.5，下柱 Ø6.4/通孔 Ø3.4，按钮孔 Ø9.4。请重点审核大平板翘曲、筋路完整性、薄壁完整性、深孔清粉和孔径偏差；未经确认不要自动加厚、封孔或修改模型。首套不喷漆，所有孔和内腔需清粉。两个零件的预览外包络均应约为 106.6 × 109.5 × 26.8 mm；上壳/下壳体积应约为 24.13/23.02 cm³。

如果工程师认为 `1.2 mm` 平板不可稳定制造，要求对方给出工艺原因和建议最小值，再修改 CAD。不要允许平台只对局部“自动加厚”，否则仓库参数、STEP 和实物将失去对应关系。

## 8. 收货后的处理

1. 签收后先拍照检查裂纹、缺角、分层、翘曲和孔内残粉；工业平台有售后时限，应在平台规定时间内反馈。嘉立创当前须知要求签收后 3 日内反馈少件、变形或坏件。[嘉立创下单须知](https://www.jlc-3dp.cn/technicalColumnsDetails/40026.html)
2. 用卡尺记录两个零件的 X/Y 外尺寸、四孔中心关系、板面平面度和壳体总高。
3. 先用手清理粉末、拉丝和毛边。不要用电钻高速强行扩孔；需要修孔时用对应钻头或铰刀手动、低速并从非外观面进入。
4. `Ø3.4 mm` 下孔可清到螺钉自由通过；`Ø2.5 mm` 上导孔在紧固件方案确定前不要随意扩大。
5. `Ø9.4 mm` 按钮孔只去除毛边，先记录原始孔径，再判断是否需要极少量修整。
6. 清粉、清屑后再让主板接近壳体。尼龙粉末和塑料切屑不得留在 PCB、接口或风扇内。

## 9. 推荐的螺钉试装方案

当前 CAD 为：下壳 `Ø3.4 mm` 通孔，上壳 `Ø2.5 mm` 导孔，柱外径 `Ø6.4 mm`，底面没有螺钉头沉孔。

第一次可准备：

- `M3 × 18 mm` 盘头或圆头机螺钉 4 枚；
- M3 平垫圈 4 枚；
- M3 手用丝锥及手柄；
- 备选 `M3 × 20 mm`，只在确认不会顶到底/顶到顶板后使用。

从底板外表面到 PCB 顶面约 `13 mm`，`M3 × 18 mm` 理论上可在上柱获得约 `5 mm` 啮合；垫圈会略微减少啮合量。PA12 或 PETG 上柱可在确认孔位和壁厚后手工攻 M3 螺纹，再使用机螺钉低扭矩夹紧。不要用电动工具直接把普通机螺钉暴力拧入 `Ø2.5 mm` 导孔。

注意：

- 当前没有沉头结构，不能用沉头螺钉强行楔入；盘头/圆头会突出底面。
- 热熔螺母的外径、长度和安装余量尚未进入 CAD，不要直接把 M3 热熔螺母熔进当前 `Ø6.4 mm` 柱。
- 塑料专用 PT 自攻螺钉需要按具体牙型重新核对底孔，不能只凭“M3”三个字替代计算。
- 如果需要成品底面平放，下一版应增加螺钉头沉孔或脚垫，而不是在本版上强行沉头。

## 10. 正确的装配和验收顺序

### A. 无主板检查

1. 将上下壳空合，观察六段接缝是否能自然闭合。
2. 不使用螺钉，检查四柱能否同轴接近；不能靠扭壳对齐。
3. 将原按钮装入 `Ø9.4 mm` 孔，确认可自由滑动和回弹。
4. 用实际 USB、HDMI、网线、DC 和耳机插头逐孔插入，先确认壳体孔本身没有明显毛边阻挡。

### B. 主板无电试装

1. 断开所有电源、存储和外设，先把原按钮装入上壳。
2. 按项目装配逻辑，将主板先放入上壳；不得压风扇、鳍片或接口来迫使四孔就位。
3. 观察两个 06 USB 是否先到达墙面基准，确认板载开关触点没有进入墙体，也没有在静止状态被按钮持续压住。
4. 安装下壳，使四颗螺钉先都只啮合 1～2 圈；按对角顺序逐步、低扭矩收紧。
5. 如果任一角必须明显压弯 PCB 才能进孔，立即停止。螺钉用于夹紧，不用于把错误孔距拉到一起。
6. 逐一插入所有实际线缆，确认插头外壳、应力释放胶套和卡扣都有空间；不能只看金属接口鼻端能否穿孔。

### C. 按钮专项验收

1. 未通电时按压至少 25 次，感受每次是否有清晰触发和完整回弹。
2. 松手后板载开关必须完全释放；轻触外按钮侧面或晃动机壳不得自行触发。
3. 若装上侧壳后按钮持续顶住开关、无行程或孔内卡滞，停止使用并记录：按钮外露量、静止间隙、触发行程和回弹情况。
4. 当前照片推导的外墙面到开关触点为约 `2.6～3.4 mm`，不能替代对原按钮隐藏顶杆长度的实测。

### D. 通电验收

只有在无电检查全部通过后才通电：

1. 确认内部无尼龙粉、塑料丝、金属屑和遗落螺钉。
2. 确认风扇进气圆孔、04 鳍片排风通道和叶轮均无阻挡。
3. 首次开机保持外壳可随时断电，不要无人值守。
4. 先做 10～15 分钟空闲测试，再做 30～60 分钟逐步负载测试，记录环境温度、CPU/SSD 温度、风扇转速和壳体是否软化或翘曲。
5. 出现异味、按钮误触、风扇摩擦、接口断连、PCB 弯曲或局部异常升温时立即断电。

## 11. 建议记录的试装结果

每次打印至少保存以下信息：

```text
日期：
平台/打印机：
工艺与材料：
材料品牌/平台材料名：
喷嘴与层高（FDM）：
模型是否缩放：
上壳实测 X/Y/Z：
下壳实测 X/Y/Z：
板面最大翘曲：
05/07 插入阻力：
04/06 接口干涉位置：
四孔是否自然同轴：
按钮孔实测：
按钮静止/触发/回弹结果：
各接口插拔结果：
使用的螺钉、长度、垫圈和攻丝方式：
通电温度和持续时间：
照片文件名：
```

一次失败打印仍然有价值，前提是记录原始尺寸和失败位置。不要只留下“磨一磨就装上了”的结论。

## 12. 下单前最终清单

- [ ] 只上传上壳和下壳两个独立 STL
- [ ] 单位为 mm，缩放为 100%，没有镜像
- [ ] 每件预览尺寸约 `106.6 × 109.5 × 26.8 mm`
- [ ] 首次材料选 PETG，或由工程师确认后选 PA12S/PA12
- [ ] 已删除平台中旧的无筋同名文件，并重新上传本版；体积约为上壳 `24.13 cm³`、下壳 `23.02 cm³`
- [ ] 平台已书面确认基础 `1.2 mm`、带 `1.5 × 0.8 mm` 内筋的大平板和 `1.8 mm` 侧壁可制造
- [ ] 平台不会擅自加厚、封孔或缩放
- [ ] 第一套不喷漆、不做厚涂层
- [ ] 已知 `0.20 mm` 侧向余量和零接缝小于常见制造波动
- [ ] 已知 HDMI 真实鼻端覆盖尚未计算
- [ ] 已准备先无电试装，再做按钮和线缆检查
- [ ] 已准备记录尺寸，而不是用强装和打磨掩盖问题

## 参考资料

- [嘉立创：3D 打印下单前必看](https://www.jlc-3dp.cn/technicalColumnsDetails/40026.html)
- [嘉立创：PA12S 尼龙材料与设计能力](https://www.jlc-3dp.cn/technicalColumnsDetails/60903.html)
- [嘉立创：PA12 尼龙材料说明](https://www.jlc-3dp.cn/technicalColumnsDetails/61261.html)
- [嘉立创：类 ABS40 功能树脂说明](https://www.jlc-3dp.cn/technicalColumnsDetails/56911.html)
- [云工厂：3D 打印工艺与材料入口](https://yungongchang.com/zh-cn/)
- [Bambu Lab：PETG HF 材料数据和打印条件](https://eu.store.bambulab.com/en-mt/products/petg-hf)

平台能力、材料名称、报价和交期会变化；以上链接与建议按 2026-08-21 可见官方资料整理。实际订单以平台当次工程审核和书面确认结果为准。

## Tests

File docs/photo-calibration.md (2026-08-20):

# 04/06 原壳面板照片描摩记录

更新日期：2026-08-20

本文档记录 [机箱盒子04.jpg](../pics/机箱盒子04.jpg) 和 [机箱盒子06.jpg](../pics/机箱盒子06.jpg) 中可见的面板开孔。机器可读数据见 [photo-calibration.json](./photo-calibration.json)，复现脚本是 [calibrate_photos.py](../scripts/calibrate_photos.py)。

## 方法边界

- 粉红线直接描摩原壳照片中的开孔轮廓。
- 黄色框是手工复核的像素包围框。
- 青色网格只在单个开孔附近表示 1 mm 尺寸，比例由该孔已确认的宽/高反求。
- 不同孔的局部网格不是同一个坐标系，不能用来换算孔间距或 PCB 坐标。
- 照片网格叠图保留照片透视，**只作轮廓证据**，不是后续 CAD 的孔位输入。
- `04/06-interface-reference.png` 已与照片叠图分离：它们使用 PCB 基准、正投影和统一毫米比例。

照片像素数据保存在 [n305_photo_reference.py](../src/n305_photo_reference.py)；机械开孔数据独立保存在 [n305_panel_reference.py](../src/n305_panel_reference.py)。

## 04 孔边像素记录

| 开孔 | 主包围框 `(x0,y0,x1,y1)` / px | 尺寸 / mm | 说明 |
| --- | --- | ---: | --- |
| DC | `(602,1890,801,2089)` | Ø5.9 | 用户确认 |
| HDMI 1 | `(953,1908,1465,2095)` | 16.5 × 5.8 | 用户确认；六边轮廓直接描摩 |
| 耳机孔 | `(1132,1625,1301,1797)` | 约 Ø5.4 | 借用相邻 HDMI 1 局部像素比例，待实物确认 |
| RJ45 主窗 | `(1586,1785,2047,2093)` | 15.0 × 10.0 | 用户确认 |
| RJ45 底部 relief | 由主窗中心向下构造 | 4.5 × 1.0 | **在主窗下方额外增加** |
| 叠层双 USB | `(2179,1698,2614,2150)` | 14.0 × 14.5 | 用户确认 |
| HDMI 3 | `(2778,1925,3308,2113)` | 16.5 × 5.8 | 用户确认；六边轮廓直接描摩 |

## RJ45 修正

旧图把 1 mm relief 包含在 10 mm 总高内，等价于把主窗压缩成 9 mm，这是错的。

当前语义是：

```text
15.0 x 10.0 mm RJ45 主窗
          +
主窗下方 4.5 x 1.0 mm relief

总包围高度 = 11.0 mm
```

原始放大图：[RJ45 raw crop](../previews/calibration/original-case-04-rj45-raw.png)。

## 与正投影开孔参考的关系

[04-interface-reference.png](../previews/reference/04-interface-reference.png) 不再使用照片包围框进行孔位排布或显示缩放。它使用：

- PCB `105.5 × 1.5 mm` 边界作为 Y/Z 基准；
- 已记录的 PCB 对齐 03 平面中心 Y；
- 04 实测侧视标定中心 Z；
- 用户确认的毫米孔尺寸；
- 原壳照片中的 HDMI 六边形、RJ45 relief 等形状证据。

因此照片决定“是什么轮廓”，但不决定“在机械图上有多大或是否倾斜”。

## 06 孔边像素记录

06 照片轮廓数据来自 [机箱盒子06.jpg](../pics/机箱盒子06.jpg) 的 4096 × 3072 原始像素。这些数据只用来确认“两个圆角 USB 孔 + 一个圆形按钮孔”，不把透视斜度传入 CAD 参考。

| 开孔 | 主包围框 `(x0,y0,x1,y1)` / px | 尺寸 / mm | 轮廓处理 |
| --- | --- | ---: | --- |
| 照片左侧 USB | `(1235,1674,1650,1865)` | 12.8 × 5.5 | 照片四边形 + 照片圆角 |
| 照片右侧 USB | `(1851,1689,2262,1876)` | 12.8 × 5.5 | 独立照片四边形 + 照片圆角 |
| 电源开关孔 | `(2722,1657,3032,1962)` | Ø9.4 | 照片中的椭圆投影，物理语义为圆孔 |

照片中两个 USB 包围框顶边相差 15 px，这是透视、镜头和面板姿态共同造成的投影差，不能当作机械高度差。两只相同 USB 焊接在同一 PCB 基准面，正投影参考强制共用 `Z=-3.14 mm`；该值只是原两项照片估计的平均值，保留整体孔组位置，不声称是独立实测。两个孔均为水平 `12.8 × 5.5 mm`、R0.7 圆角矩形。

测量规则：相同器件位于同一安装层时，默认共享相同的机械高度参数。只有卡尺、深度尺、正投影标定或明确的器件料号/封装差异才能打破该约束；单张斜拍照片中的像素高差只能记录为透视观测，不得直接写入 CAD 参数。

审图文件：

- [06 原壳局部 1 mm 网格](../previews/calibration/original-case-06-1mm-grid.png)
- [06 面板正投影 CAD 参考](../previews/reference/06-interface-reference.png)
- [左侧 USB 原始裁图](../previews/calibration/original-case-06-usb_left-raw.png)
- [右侧 USB 原始裁图](../previews/calibration/original-case-06-usb_right-raw.png)
- [电源开关孔原始裁图](../previews/calibration/original-case-06-power_switch-raw.png)

## 复现

```bash
python scripts/calibrate_photos.py
python scripts/render_mainboard_reference.py
```

命令生成 04/06 的 PNG/JSON，不生成 STEP/STL。

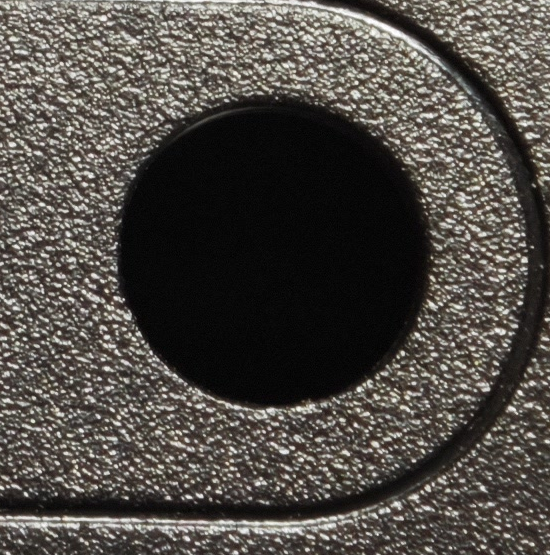
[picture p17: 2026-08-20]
previews/calibration/original-case-06-power_switch-raw.png

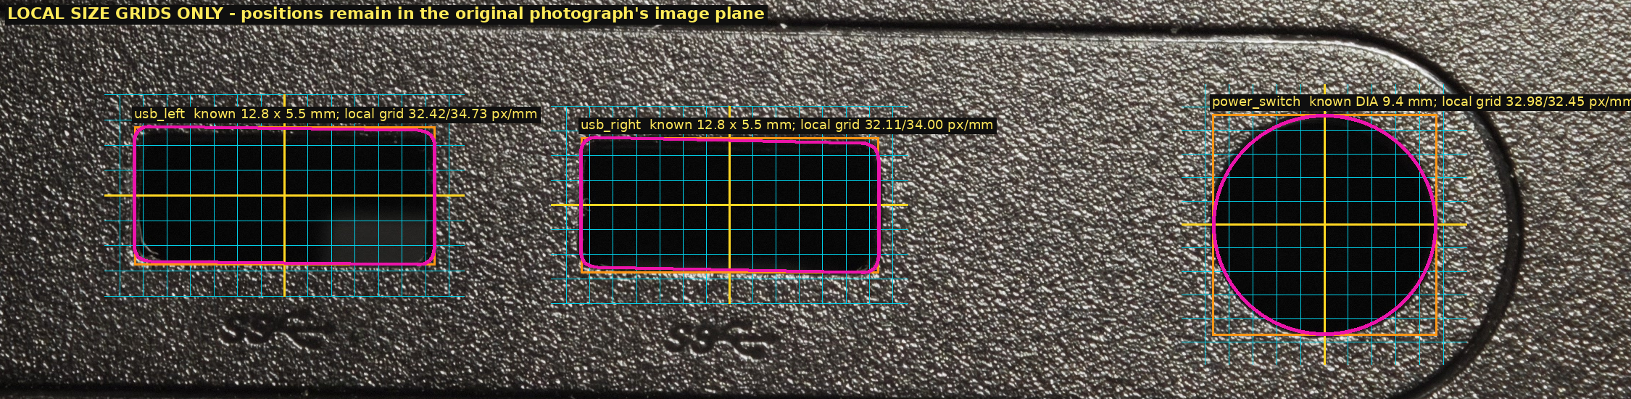
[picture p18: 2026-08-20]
previews/calibration/original-case-06-1mm-grid.png

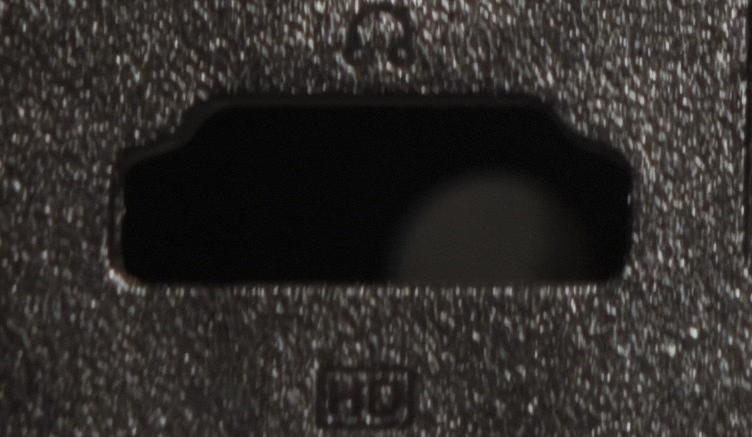
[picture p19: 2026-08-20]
previews/calibration/original-case-04-hdmi_1-raw.png

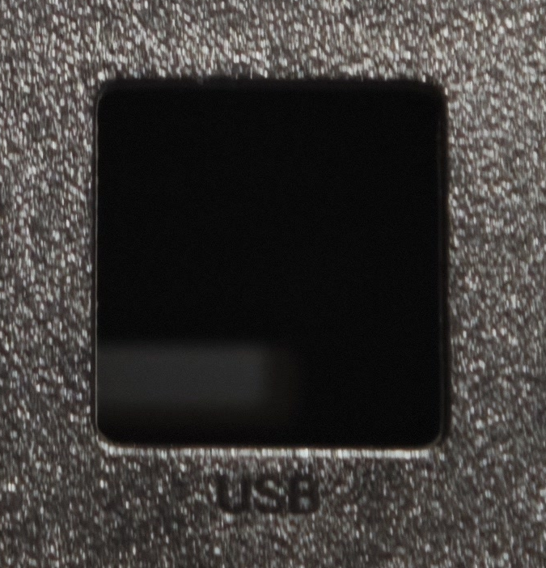
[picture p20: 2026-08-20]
previews/calibration/original-case-04-stack_dual_usb-raw.png

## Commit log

2026-08-20 update code
    [fan_mesh_cut_41p2mm.dxf, n305_board_keepout_reference.step, n305_board_keepout_reference.stl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]
2026-08-20 Build validated N305 V2 enclosure prototype
    [n305_connectors_and_switch.step, n305_connectors_and_switch.stl, n305_cooling_assembly.step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]
